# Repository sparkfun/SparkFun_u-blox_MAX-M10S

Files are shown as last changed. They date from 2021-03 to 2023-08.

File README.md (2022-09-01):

SparkFun GNSS Receiver Breakout - MAX-M10S (Qwiic)
===========================================================

SparkFun GNSS Receiver Breakout - MAX-M10S (Qwiic) (https://www.sparkfun.com/products/18037)

[*SparkFun GNSS Receiver Breakout - MAX-M10S (Qwiic) (GPS-18037)*](https://www.sparkfun.com/products/18037)

The SparkFun MAX-M10S Breakout is an ultra-low-power, high performance, miniaturized GNSS board that is perfect for battery operated applications that don't possess a lot of space, such as asset trackers and wearable devices. The MAX-M10S module from u-blox has an extremely low power consumption that is less than 25mW in continuous tracking mode.

The on-board MAX-M10S GNSS receiver can receive signals from the GPS, GLONASS, BeiDou, and Galileo constellations. Thanks to the u-blox Super-S technology, the module offers improved RF sensitivity with small antennas and in non-line-of-sight scenarios. We've included an SMA connector for a sturdy connection when attaching an external antenna. The board is also equipped with an on-board rechargeable battery that provides backup power to the module's RTC. This reduces the time-to-first fix from a cold start (~24s) to a hot start (~1s). The battery will maintain RTC and GNSS orbit data without being connected to power for up to five hours. This increases precision and decreases lock time in battery operated devices without compromising GNSS performance.

Additionally, this u-blox receiver supports I2C which makes it perfect for Qwiic compatibility so we don't have to use up our precious UART ports. Utilizing our handy Qwiic system, no soldering is required to connect it to the rest of your system. However, we still broke out 0.1"-spaced pins in case you prefer to use a breadboard. For users that prefer to communicate over UART, we made sure to configure the UART pin grouping to an industry standard to ensure that it easily connects to a Serial Basic.

U-blox based GNSS products are configurable using the popular Windows program called u-center. Plenty of different functions can be configured on the MAX-M10S: baud rates, update rates, spoofing detection, external interrupts, etc. We've also written an extensive Arduino library for u-blox modules to make reading and controlling the MAX-M10S over our Qwiic Connect System easy. Leave NMEA behind! Start using a much lighter weight binary interface and give your microcontroller (and its one serial port) a break. The SparkFun Arduino library shows how to read latitude, longitude, even heading and speed over I2C without the need for constant serial polling.

Repository Contents
-------------------

* **/Documents** - Related U-blox datasheets and various whitepapers 
* **/Hardware** - Eagle files

Documentation
--------------

* **[Installing an Arduino Library Guide](https://learn.sparkfun.com/tutorials/installing-an-arduino-library)** - Basic information on how to install an Arduino library.
* **[Arduino Library](https://github.com/sparkfun/SparkFun_u-blox_GNSS_Arduino_Library)** - Arduino Library for u-blox modules.
* **[Hookup Guide](https://learn.sparkfun.com/tutorials/1759)** - Hookup guide for the SparkFun GNSS Receiver Breakout - MAX-M10S (Qwiic).

Product Versions
----------------
* [GPS-18037](https://www.sparkfun.com/products/18037)

Version History
---------------
* v1.0 - Initial Release

License Information
-------------------

This product is _**open source**_! 

Various bits of the code have different licenses applied. Anything SparkFun wrote is beerware; if you see me (or any other SparkFun employee) at the local, and you've found our code helpful, please buy us a round!

Please use, reuse, and modify these files as you see fit. Please maintain attribution to SparkFun Electronics and release anything derivative under the same license.

Distributed as-is; no warranty is given.

- Your friends at SparkFun.

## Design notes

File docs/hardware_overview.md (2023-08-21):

We've broken out the u-blox MAX-M10S module to a breakout. This section highlights the relevant features of the board. For more information about the IC, check out the Resources and Going Further.

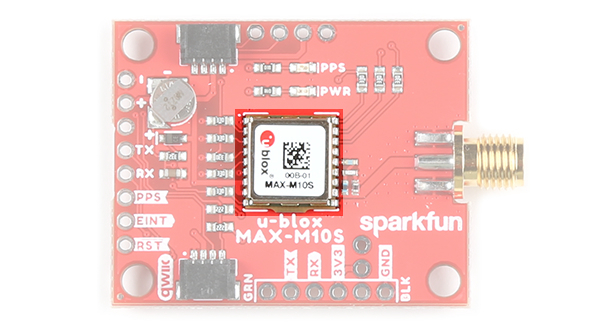
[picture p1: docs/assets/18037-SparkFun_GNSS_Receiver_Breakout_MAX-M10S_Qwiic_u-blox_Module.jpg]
MAX-M10S Highlighted
<div style="text-align: center"></div>

### Power

Power for this board should be **3.3V**. There is a 3.3V pin on the PTH header along the side of the board, but you can also provide power through the Qwiic connector.

<table class="table table-hover table-striped table-bordered">
  <tr style="vertical-align:middle;">
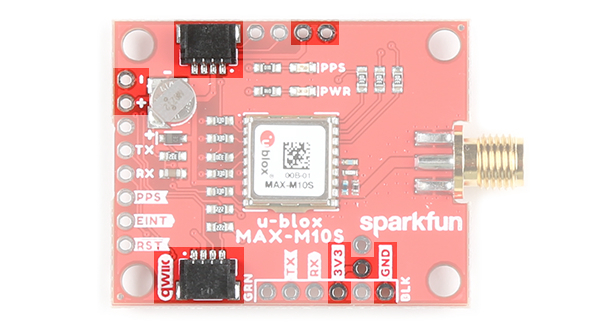
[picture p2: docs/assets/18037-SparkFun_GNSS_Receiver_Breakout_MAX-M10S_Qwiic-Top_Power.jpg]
Top View of Power Highlighted
   <td style="text-align: center; vertical-align: middle;"></td>
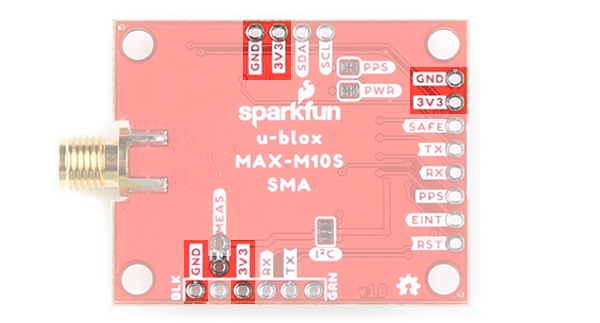
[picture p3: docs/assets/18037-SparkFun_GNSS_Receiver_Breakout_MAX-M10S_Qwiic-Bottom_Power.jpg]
Bottom View of Power Highlighted
   <td style="text-align: center; vertical-align: middle;"></td>
  </tr>
  <tr style="vertical-align:middle;">
  <td style="text-align: center; vertical-align: middle;"><i>Top View</i></td>
  <td style="text-align: center; vertical-align: middle;"><i>Bottom View</i></td>
  </tr>
</table>

### Communication Ports

!!! note
    The MAX-M10S differs from other modules as it only has I<sup>2</sup>C and UART. It is important to note that the board does not have SPI pins.

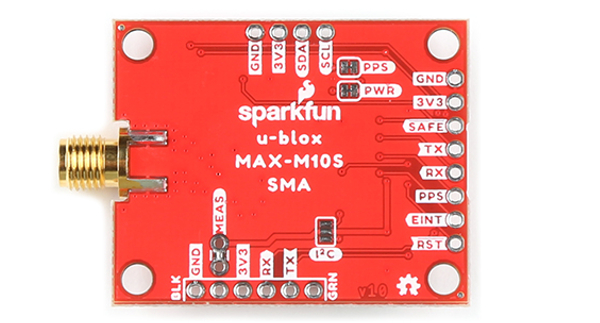
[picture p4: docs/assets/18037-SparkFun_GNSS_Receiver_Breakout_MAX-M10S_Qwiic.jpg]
Back of Board I2C and UART Ports, but no SPI
<div style="text-align: center"></a></div>

### Qwiic and I<sup>2</sup>C (a.k.a. DDC)

There are two PTHs labeled `SDA` and `SCL` which indicates the I<sup>2</sup>C data lines. Similarly, you can just use the Qwiic connector to provide power and connect to the I<sup>2</sup>C pins. The [Qwiic ecosystem](https://www.sparkfun.com/qwiic) is made for fast prototyping by removing the need for soldering. All you need to do is plug a Qwiic cable into the Qwiic connector and voila!

<table class="table table-hover table-striped table-bordered">
  <tr style="vertical-align:middle;">
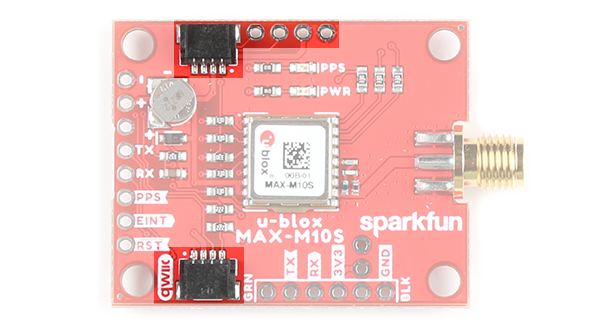
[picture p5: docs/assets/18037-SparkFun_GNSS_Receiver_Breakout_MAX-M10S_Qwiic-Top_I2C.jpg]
Top View of I2C
   <td style="text-align: center; vertical-align: middle;"></td>
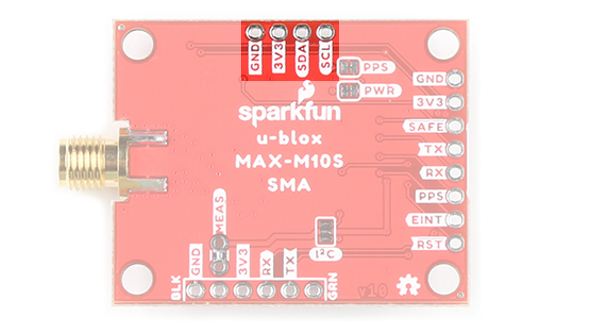
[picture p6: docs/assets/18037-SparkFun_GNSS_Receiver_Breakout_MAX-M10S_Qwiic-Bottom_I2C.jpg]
Bottom View of I2C
   <td style="text-align: center; vertical-align: middle;"></td>
  </tr>
  <tr style="vertical-align:middle;">
  <td style="text-align: center; vertical-align: middle;"><i>Top View</i></td>
  <td style="text-align: center; vertical-align: middle;"><i>Bottom View</i></td>
  </tr>
</table>

!!! note
    The only I2C address for this and all u-Blox GPS products is <b>0x42</b>, though each can have their address changed through software.

### UART

For users that prefer to communicate over UART, we made sure to configure the UART pin grouping to an industry standard to ensure that it easily connects to a [Serial Basic](https://www.sparkfun.com/products/15096). Extra UART pins are also broken out on another edge of the board as well. The port is set to **38400 baud** as the default.

<table class="table table-hover table-striped table-bordered">
  <tr style="vertical-align:middle;">
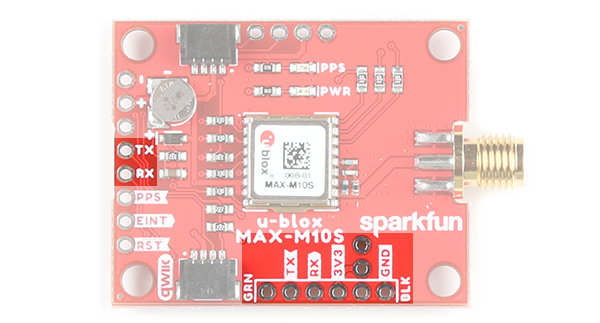
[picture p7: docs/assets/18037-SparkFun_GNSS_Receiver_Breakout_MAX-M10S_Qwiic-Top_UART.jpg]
Top View of UART
   <td style="text-align: center; vertical-align: middle;"></td>
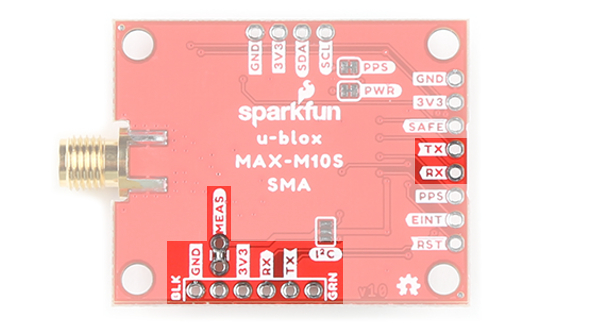
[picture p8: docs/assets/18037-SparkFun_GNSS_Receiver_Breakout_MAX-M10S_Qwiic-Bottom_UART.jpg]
Bottom View of UART
   <td style="text-align: center; vertical-align: middle;"></td>
  </tr>
  <tr style="vertical-align:middle;">
  <td style="text-align: center; vertical-align: middle;"><i>Top View</i></td>
  <td style="text-align: center; vertical-align: middle;"><i>Bottom View</i></td>
  </tr>
</table>

### Control Pins

These pins are used for various extra control of the MAX-M10S. The control pins are highlighted below.

<table class="table table-hover table-striped table-bordered">
  <tr style="vertical-align:middle;">
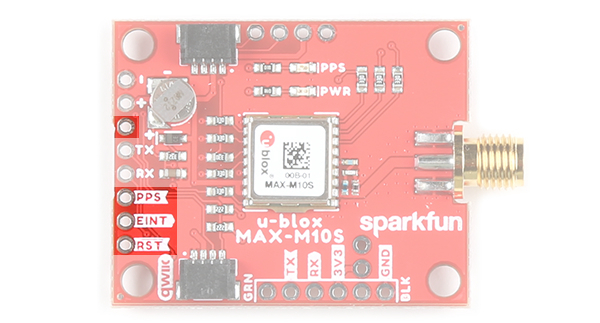
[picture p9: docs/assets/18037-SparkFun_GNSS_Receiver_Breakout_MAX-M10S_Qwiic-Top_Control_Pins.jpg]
Top View of Control Pins
   <td style="text-align: center; vertical-align: middle;"></td>
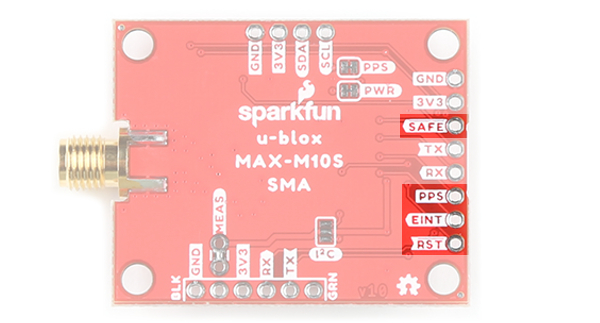
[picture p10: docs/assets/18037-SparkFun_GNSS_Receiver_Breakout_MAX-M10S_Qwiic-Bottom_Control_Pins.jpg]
Bottom View of Control Pins
   <td style="text-align: center; vertical-align: middle;"></td>
  </tr>
  <tr style="vertical-align:middle;">
  <td style="text-align: center; vertical-align: middle;"><i>Top View</i></td>
  <td style="text-align: center; vertical-align: middle;"><i>Bottom View</i></td>
  </tr>
</table>

* **PPS:** Pulse-per-second output pin. Begins blinking at 1Hz when module gets basic GPS/GNSS position lock.
* <b><span style="text-decoration: overline">RST</span>:</b> Reset input pin. Pull this line low to reset the module.
* <b><span style="text-decoration: overline">SAFE</span>:</b> Safeboot input pin. This is required for firmware updates to the module and generally should not be used or connected. To save on space, the silkscreen is labeled on the bottom of the board.
* **EINT:** Interrupt input/output pin. Can be configured using U-Center to bring the module out of deep sleep or to output an interrupt for various module states.

### SMA Connector for Antenna

The board is populated with an SMA connector for a secure connection to a patch antenna.

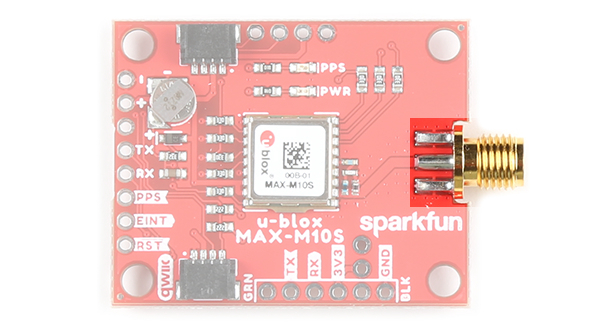
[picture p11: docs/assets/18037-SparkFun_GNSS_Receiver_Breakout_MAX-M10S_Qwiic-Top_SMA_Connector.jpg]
SMA Antenna
<div style="text-align: center"></div>

### LEDs

The board includes two status LEDs as indicated in the image below.

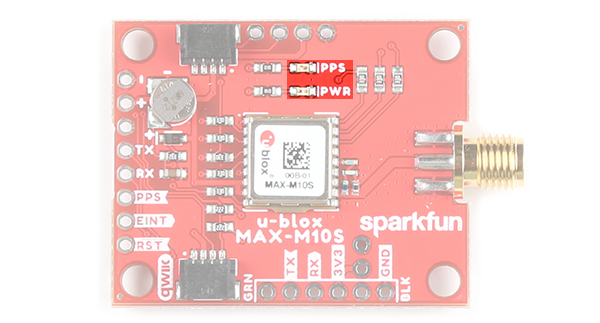
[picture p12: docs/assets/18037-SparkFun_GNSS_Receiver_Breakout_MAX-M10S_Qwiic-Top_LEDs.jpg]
LEDs
<div style="text-align: center"></div>

* **PPS:** The pulse per second LED will illuminate each second once a position lock has been achieved.
* **PWR:** The power LED will illuminate when 3.3V is provided either over the Qwiic bus or any of the 3.3V PTH pins.

### Jumpers

There are four jumpers on the back of the board. For more information, check out our [tutorial on working with jumper pads and PCB traces](https://learn.sparkfun.com/tutorials/how-to-work-with-jumper-pads-and-pcb-traces/all) should you decide to cut the traces with a hobby knife.

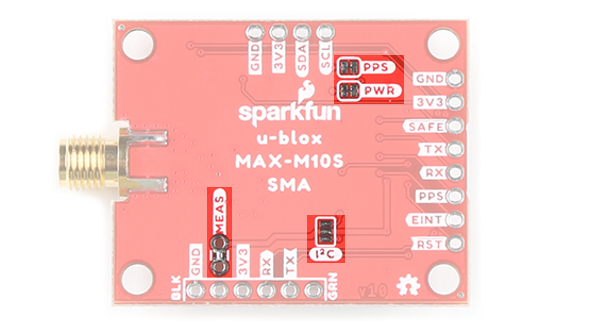
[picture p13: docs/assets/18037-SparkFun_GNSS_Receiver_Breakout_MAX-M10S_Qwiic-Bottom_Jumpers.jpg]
Jumpers
<div style="text-align: center"></div>

* **PWR:** This is connected to the PWR LED on the top of the board. Cutting this disables the LED.
* **MEAS:** Short for current measurement. By default, the MEAs is closed. Cutting the jumper and soldering to the PTH pads will allows you to insert a current meter and precisely monitor the how much current your application is consuming.
* **PPS:** This is connected to the PPS LED on the top of the board. Cutting this disables the LED.
* **I<sup>2</sup>C:** The I<sup>2</sup>C jumpers are open by default. By adding solder to the jumpers, it will connect to the 2.2k&ohm; pull-up resistors for the I<sup>2</sup>C bus.  Most of the time you can leave these alone unless your project requires you to [connect the pull-up resistors](https://learn.sparkfun.com/tutorials/i2c/all#i2c-at-the-hardware-level).

### Backup Battery

The MS621FE rechargeable battery maintains the battery backed RAM (BBR) on the GNSS module. This allows for much faster position locks (a.k.a. hot start). The BBR is also used for module configuration retention. The battery is automatically trickle charged when power is applied and should maintain settings and GNSS orbit data for up to two weeks without power.

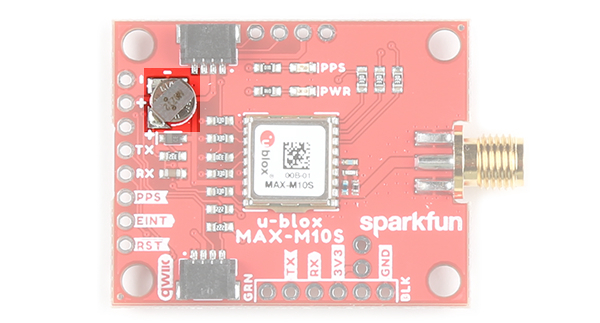
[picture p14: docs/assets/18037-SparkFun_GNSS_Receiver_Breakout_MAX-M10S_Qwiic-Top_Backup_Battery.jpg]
Backup Battery
<div style="text-align: center"></div>

### Board Dimensions

The overall length and width with the antenna connector is about 1.74" x 1.20". There are four mounting holes by each corner of the board.

<div style="text-align: center"><a href="https://cdn.sparkfun.com/assets/e/8/8/9/8/SparkFun_u-blox_MAX-M10S_Board_Dimensions.png">Board Dimensions</a></div>

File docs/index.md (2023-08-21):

<p align="center">
  <a href="https://github.com/sparkfun/SparkFun_u-blox_MAX-M10S/issues" alt="Issues">
    </a>
  <a href="https://github.com/sparkfun/SparkFun_u-blox_MAX-M10SC/actions" alt="Actions">
    </a>
  <a href="https://github.com/sparkfun/SparkFun_u-blox_MAX-M10S/blob/main/LICENSE.md" alt="License">
    </a>
  <a href="https://twitter.com/intent/follow?screen_name=sparkfun">
    </a>
</p>

The [SparkFun u-blox MAX-M10S breakout](https://www.sparkfun.com/products/18037) is an ultra-low-power, high performance, miniaturized GNSS board that is perfect for battery operated applications that don't possess a lot of space, such as asset trackers and wearable devices. In this tutorial, we will quickly get you set up using the Qwiic ecosystem and Arduino so that you can start reading the output!

<div style="text-align: center">
  <table style="border-style:none">
    <tr>
      <td style="text-align: center; vertical-align: middle;">
        <a href="https://www.sparkfun.com/products/18037">
          <div style="text-align: center">SparkFun GNSS Receiver Breakout - MAX-M10S (Qwiic)</div>
          <h3 style="text-align: left">SparkFun GNSS Receiver Breakout - MAX-M10S (Qwiic)
          </h3>
        </a>
        <div style="text-align: left"><span style="text-align: left">GPS-18037</span></div>
      </td>
    </tr>
  </table>
  </div>

<div style="text-align: center"><iframe width="600" height="328" src="https://www.youtube.com/embed/Yh8pLKs7aaY" title="Product Showcase: SparkFun GNSS Receiver MAX-M10S" frameborder="0" allow="accelerometer; autoplay; clipboard-write; encrypted-media; gyroscope; picture-in-picture" allowfullscreen></iframe></div>

### Required Materials

To follow along with this tutorial, you will need the following materials. You may not need everything though depending on what you have. Add it to your cart, read through the guide, and adjust the cart as necessary.

<div>
<table style="border-style:none">
    <tr>
        <td width="140">
            <a href="https://www.sparkfun.com/products/18037">
              <div style="text-align: center">SparkFun GNSS Receiver Breakout - MAX-M10S (Qwiic)</div>
              <h3 style="text-align: left">SparkFun GNSS Receiver Breakout - MAX-M10S (Qwiic)</h3>
            </a>
            <span>GPS-18037</span>
        </td>
        <td width="140">
            <a href="https://www.sparkfun.com/products/14986">
              <div style="text-align: center">GPS/GNSS Magnetic Mount Antenna - 3m (SMA)</div>
              <h3 style="text-align: left">GPS/GNSS Magnetic Mount Antenna - 3m (SMA)</h3>
            </a>
            <span>GPS-14986</span>
        </td>
        <td width="140">
            <a href="https://www.sparkfun.com/products/18158">
              <div style="text-align: center">SparkFun RedBoard Plus</div>
              <h3 style="text-align: left">SparkFun RedBoard Plus</h3>
            </a>
            <span>DEV-18158</span>
        </td>
        <td width="140">
            <a href="https://www.sparkfun.com/products/14426">
              <div style="text-align: center">Qwiic Cable - 50mm</div>
              <h3 style="text-align: left">Qwiic Cable - 50mm</h3>
            </a>
            <span>PRT-14426</span>
        </td>
    </tr>
    <tr>
    <td width="140">
        <a href="https://www.sparkfun.com/products/15424">
          <div style="text-align: center">Reversible USB A to C Cable - 2m</div>
          <h3 style="text-align: left">Reversible USB A to C Cable - 2m</h3>
        </a>
        <span>CAB-15424</span>
    </td>
    </tr>
</table>
</div>

#### Additional GPS Antenna Options

Below are some other GPS antenna options.

<div class="container">
<table style="border-style:none;">
    <tr>
    <td width="140">
        <a href="https://www.sparkfun.com/products/14987">
          <div style="text-align: center">GPS/GNSS Embedded Antenna - 1m (SMA)</div>
          <h3 style="text-align: left">GPS/GNSS Embedded Antenna - 1m (SMA)</h3>
        </a>
        <span>GPS-14987</span>
    </td>
    <td width="140">
        <a href="https://www.sparkfun.com/products/177">
          <div style="text-align: center">GPS Embedded Antenna SMA</div>
            <h3 style="text-align: left">GPS Embedded Antenna SMA</h3>
        </a>
        <span>GPS-00177</span>
    </td>
    </tr>
</table>
</div>

### Suggested Reading

If you aren't familiar with the Qwiic system, we recommend reading [here for an overview](https://www.sparkfun.com/qwiic).

<div style="text-align: center">
<table style="border-style:none">
  <tr>
   <td style="text-align: center; vertical-align: middle;">
   <div style="text-align: center"><a href="https://www.sparkfun.com/qwiic">Qwiic Connect System Click to learn more about the Qwiic Connect System!</a></td></div>
  </tr>
  <tr>
    <td style="text-align: center; vertical-align: middle;"><div style="text-align: center"><i><a href="https://www.sparkfun.com/qwiic">Qwiic Connect System</a></i></div></td>
  </tr>
</table>
</div>

If you aren’t familiar with the following concepts, we also recommend checking out a few of these tutorials before continuing.

<table style="border-style:none">
    <tr>
        <td style="vertical-align: text-top;" width="264px">
            <a href="https://learn.sparkfun.com/tutorials/gps-basics">
            
            <h3 style="text-align: left">GPS Basics
            </h3></a>
        </td>
        <td style="vertical-align: text-top;" width="264px">
            <a href="https://learn.sparkfun.com/tutorials/i2c">
            
            <h3 style="text-align: left">I2C
            </h3></a>
        </td>
        <td style="vertical-align: text-top;" width="264px">
            <a href="https://learn.sparkfun.com/tutorials/serial-basic-hookup-guide">
            
            <h3 style="text-align: left">Serial Basic Hookup Guide
            </h3></a>
        </td>
        <td style="vertical-align: text-top;" width="264px">
            <a href="https://learn.sparkfun.com/tutorials/redboard-plus-hookup-guide">
            
            <h3 style="text-align: left">RedBoard Hookup Guide
            </h3></a>
        </td>
    <tr>
</table>

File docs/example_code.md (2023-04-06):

We're just going to look at example two (i.e. "**Example2_NMEAParsing.ino**") which in my opinion, makes it clear the awesomeness of these GPS receivers. That is to say, talking to satellites and finding out where in the world you are.     

``` c
#include <Wire.h> //Needed for I2C to GPS

#include "SparkFun_u-blox_GNSS_Arduino_Library.h" //Click here to get the library: http://librarymanager/All#SparkFun_u-blox_GNSS
SFE_UBLOX_GNSS myGNSS;

void setup()
{
  Serial.begin(115200);
  Serial.println("SparkFun u-blox Example");

  Wire.begin();

  if (myGNSS.begin() == false)
  {
    Serial.println(F("u-blox GNSS module not detected at default I2C address. Please check wiring. Freezing."));
    while (1);
  }

  //This will pipe all NMEA sentences to the serial port so we can see them
  myGNSS.setNMEAOutputPort(Serial);
}

void loop()
{
  myGNSS.checkUblox(); //See if new data is available. Process bytes as they come in.

  delay(250); //Don't pound too hard on the I2C bus
```

When you upload this code you'll have to wait ~24s to get a lock onto any satellites. After that first lock, the backup battery on the board will provide power to some internal systems that will allow for a **hot start** the next time you turn on the board. The **hot start** only lasts four hours, but allows you to get a lock within one second. After you get a lock the [serial terminal](https://learn.sparkfun.com/tutorials/terminal-basics/arduino-serial-monitor-windows-mac-linux) will start listing longitude and latitude coordinates, as seen below. Make sure to set the serial monitor to **115200 baud**.

<span style="display:block;text-align:center"> This image shows a screenshot of the Arduino Serial terminal spitting out latitude and longitude data. (https://cdn.sparkfun.com/assets/learn_tutorials/8/6/9/nmeaCapture-ublox2.jpg) </span>

<span style="display:block;text-align:center"> _These are the coordinates for SparkFun HQ_ </span>

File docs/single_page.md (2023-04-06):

---
hide:
  - navigation
  - toc
icon: fontawesome/solid/scroll
---

# Introduction
--8<-- "./docs/index.md"

# Hardware Overview
--8<-- "./docs/hardware_overview.md"

# Hardware Assembly
--8<-- "./docs/hardware_assembly.md"

# Software Setup and Programming
--8<-- "./docs/software_setup_and_programming.md"

# Example Code
--8<-- "./docs/example_code.md"

# Troubleshooting Tips
--8<-- "./docs/troubleshooting.md"

# Resources:
--8<-- "./docs/resources_and_going_further.md"

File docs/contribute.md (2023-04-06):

# Contribute: Help Fix our Mistake!
Spot something wrong? Feel free to contribute our open-source design and documentation. 

## Improve our Documentation
All of this documentation can be modified by you! Please help us make it better.

* These pages are contained in the [`docs` folder](https://github.com/sparkfun/SparkFun_u-blox_MAX-M10S/tree/main/docs) of the [SparkFun GNSS Receiver Breakout - MAX-M10S (Qwiic)](https://github.com/sparkfun/SparkFun_u-blox_MAX-M10S) repository.

### Submit a Correction
1. Fork this repo
2. Add your corrections or improvements to the markdown file
3. File a pull request with your changes, and enjoy making the ~~words~~ ~~worlds~~ world a better place.
    * Once received, the documentation specialist will automatically be notified.
    * We will review your suggested improvements to make sure they are correct and fit within our documentation standards.

## Improve our Hardware Design
All of our designs are open-source! Please help us make it better.

* Our board design files are contained in the [`Hardware` folder](https://github.com/sparkfun/SparkFun_u-blox_MAX-M10S/tree/main/Hardware) of the [SparkFun GNSS Receiver Breakout - MAX-M10S (Qwiic)](https://github.com/sparkfun/SparkFun_u-blox_MAX-M10S) repository. 

### Sumbit a Design Improvement
1. Fork this repo
2. Add your design improvements
3. File a pull request with your changes, and enjoy making the ~~words~~ ~~worlds~~ world a better place.
    * Once received, the engineer in charge of the original design will automatically be notified.
    * We will review your suggested improvements, if they are within our board design standards and meet our product design requirements, we will flag these changes for our next board revision. *(Please note, that even if your suggestion is accepted, these changes may not be immediate. We may have to cycle through our current product inventory first.)*

## Contributors
Let's provided some recognition to the contributors for this project!

GitHub Contributors Image
<br>


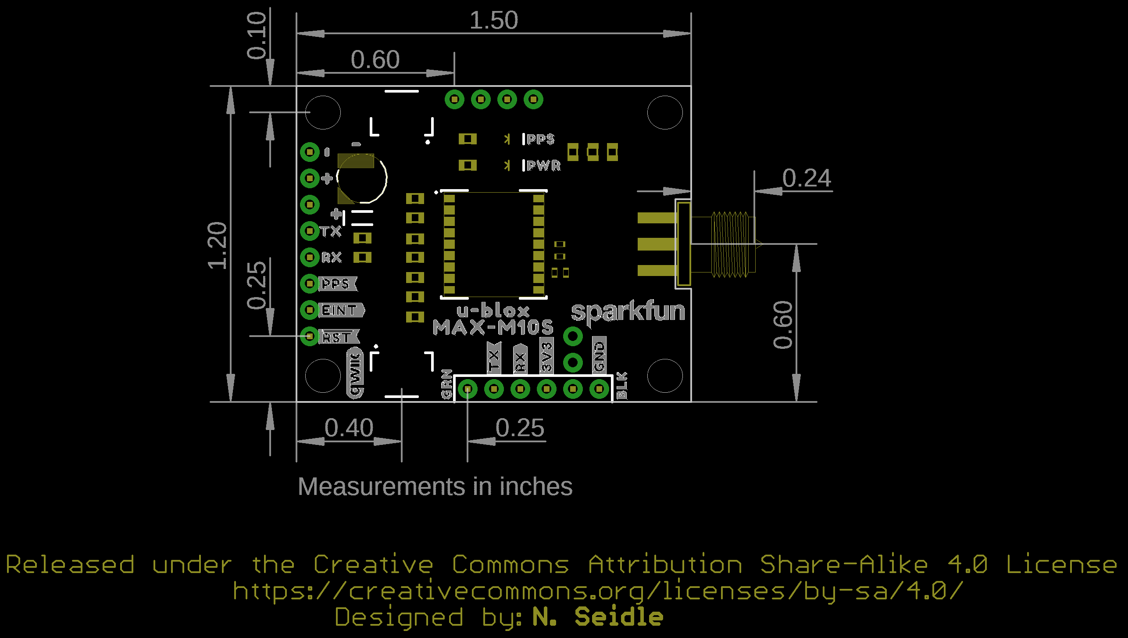
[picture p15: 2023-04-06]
Hardware/SparkFun_u-blox_MAX-M10S_Board_Dimensions.png

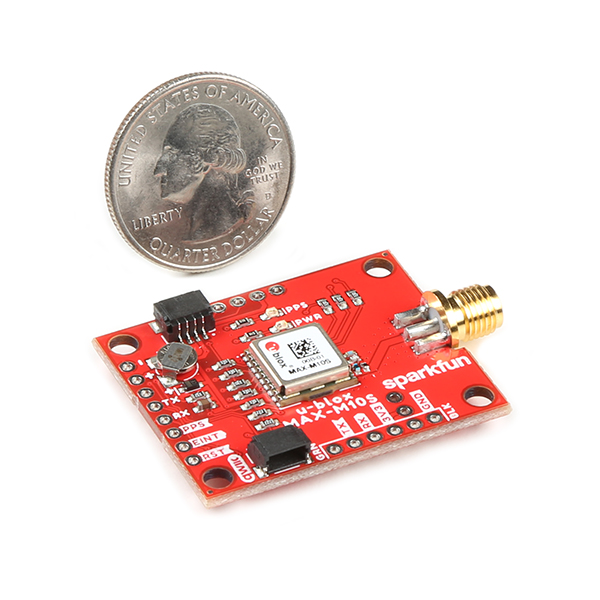
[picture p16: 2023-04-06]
docs/assets/18037-SparkFun_GNSS_Receiver_Breakout_-_MAX-M10S__Qwiic_-04.jpg

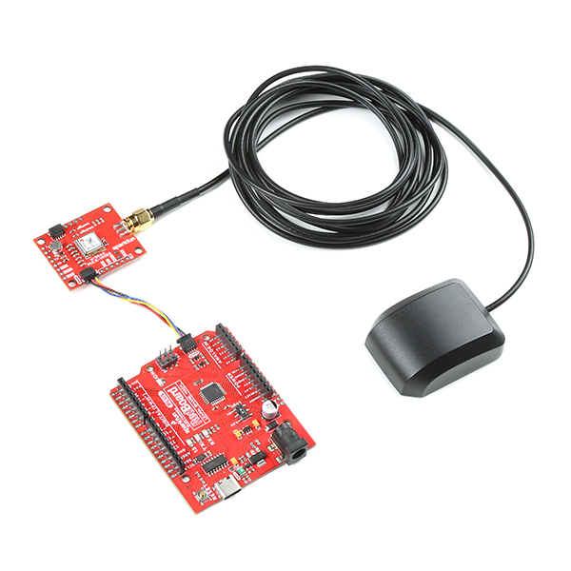
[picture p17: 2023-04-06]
docs/assets/18037-SparkFun_GNSS_Receiver_Breakout_-_MAX-M10S__Qwiic_-05.jpg

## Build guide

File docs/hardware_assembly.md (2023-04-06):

At a minimum, you will need to attach an external antenna to the MAX-M10S, supply 3.3V power, and connect to one of the board's peripherals.

### Attaching an External Antenna

Plug in one of our patch antennas with SMA connector to the GPS board. Secure the connection using the hex nut until it is finger-tight.

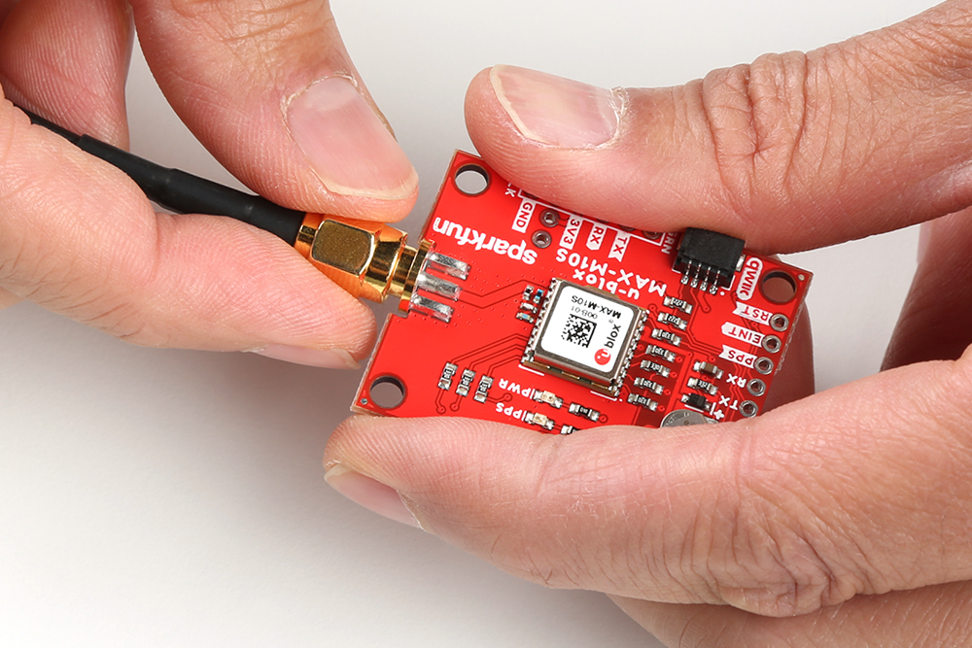
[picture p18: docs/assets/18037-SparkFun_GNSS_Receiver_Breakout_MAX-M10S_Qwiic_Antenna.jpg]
Finger Tightening the SMA GPS Antenna to the MAX-M10S
<div class="center-block text-center"></div>

### I<sup>2</sup>C

One method to communicate with the MAX-M10S is through I<sup>2</sup>C. The Qwiic connect system makes it quick and easy to connect the board to your system using a polarized cable. For embedded projects, you can use a Qwiic-enabled Arduino development board like the [RedBoard Plus](https://www.sparkfun.com/products/18158) and its [associated USB cable](https://www.sparkfun.com/products/15425). Then plug a Qwiic cable between the RedBoard Plus and the SparkFun MAX-M10S.

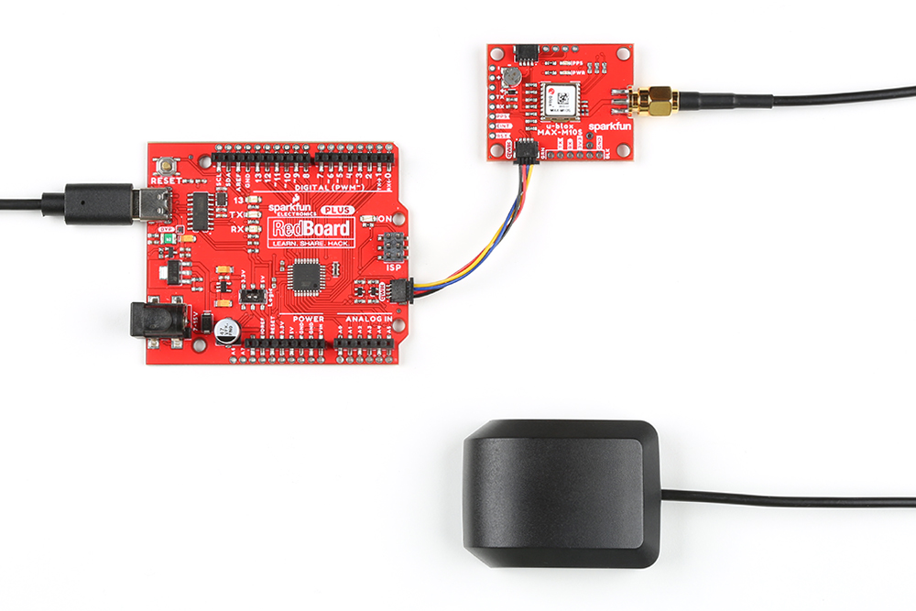
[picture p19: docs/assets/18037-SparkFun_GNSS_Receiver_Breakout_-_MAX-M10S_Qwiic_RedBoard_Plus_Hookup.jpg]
RedBoard Plus Connected to the MAX-M10S via Qwiic Cable
<div class="center-block text-center"></div>

!!! note
    The RedBoard Plus includes a switch to adjust the logic levels to either 5V or 3.3V. It does not matter what side the switch is on for this setup to communicate with the MAX-M10S since there are logic level converters included before the Qwiic connector.

If you're going to be [soldering](https://learn.sparkfun.com/tutorials/how-to-solder-through-hole-soldering) to the through hole pins for I<sup>2</sup>C functionality, then just attach the following lines between your chosen microcontroller's I<sup>2</sup>C and the MAX-M10S:

* SDA to SDA
* SCL to SCL
* 3.3V to 3.3V
* GND to GND

### UART

A second method to communicate with the MAX-M10S is through its serial UART. You can directly connect the GPS to the computer by connecting a USB-to-serial converter to the industry standard serial connection (aka the 'FTDI' pinout). In this case, we used an FTDI but you can use another USB-to-serial converter like the CH340. Just make sure to match the silkscreen (GRN to GRN and BLK to BLK). For a secure connection, you&apos;ll need to [solder](https://learn.sparkfun.com/tutorials/how-to-solder-through-hole-soldering) male header pins or wires to the MAX-M10S.

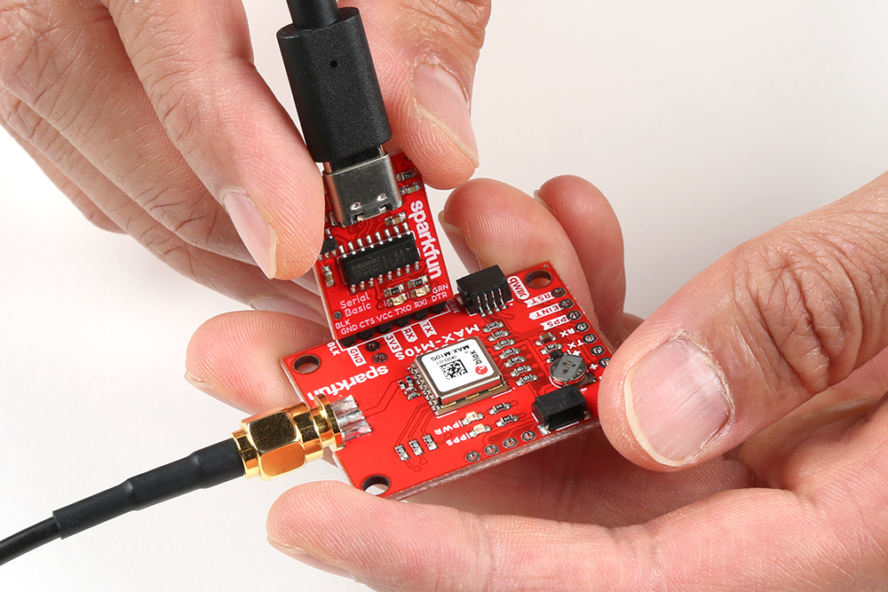
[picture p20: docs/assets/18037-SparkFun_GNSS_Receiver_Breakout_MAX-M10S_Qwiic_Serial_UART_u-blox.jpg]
USB-to-Serial Converter to MAX-M10S
<div class="center-block text-center"></div>

You could also connect the pins to a microcontroller like the RedBoard Plus as long as the switch for the logic levels are flipped to the 3.3V side before powering the board up. You'll need to do a little bit more work as opposed to using Qwiic connect system. You'll need to attach the following lines between your chosen microcontroller's UART and the MAX-M10S:

* Tx to Rx
* Rx to Tx
* 3.3V to 3.3V
* GND to GND

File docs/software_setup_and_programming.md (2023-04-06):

!!! note
    This example assumes you are using the latest version of the Arduino IDE on your desktop. If this is your first time using Arduino, please review our tutorial on <a href="https://learn.sparkfun.com/tutorials/installing-arduino-ide">installing the Arduino IDE.</a> If you have not previously installed an Arduino library, please check out our <a href="https://learn.sparkfun.com/tutorials/installing-an-arduino-library">installation guide.</a>

    If you've never connected an FTDI or CH340 to your computer before, you may need to install drivers for the USB-to-serial converter. Check out our <a href="https://learn.sparkfun.com/tutorials/how-to-install-ftdi-drivers">How to Install FTDI Drivers</a> or <a href="https://learn.sparkfun.com/tutorials/sparkfun-serial-basic-ch340c-hookup-guide#drivers-if-you-need-them">How to Install CH340 Drivers</a> tutorial for help with the installation.

All of our u-blox based GPS boards share the same library: this board, their [predeccesors](https://learn.sparkfun.com/tutorials/sparkfun-gps-breakout-zoe-m8q-and-sam-m8q-hookup-guide) and the higher [precision](https://www.sparkfun.com/products/15005) [u-blox cousins](https://www.sparkfun.com/products/15136). The SparkFun u-blox Arduino library can be downloaded with the Arduino library manager by searching '**SparkFun u-blox GNSS**' or you can grab the zip here from the [GitHub repository](https://github.com/sparkfun/SparkFun_u-blox_GNSS_Arduino_Library) to manually install:

<div style="text-align: center"><a href="https://github.com/sparkfun/SparkFun_u-blox_GNSS_Arduino_Library/archive/main.zip" class="md-button">SparkFun U-blox Arduino Library (ZIP)</a></div>

There are several example sketches provided that utilize the I<sup>2</sup>C bus to get you up and receiving messages from space. We&apos;ll go over one of the examples in this tutorial.

!!! note
    Example 2 uses the '<b>MicroNMEA</b>' library by <b>Steve Marple</b>. Make sure to install the library as well by searching for it in the Arduino library manager. You could also grab the zip here from the <a href="https://github.com/stevemarple/MicroNMEA">GitHub repository</a> to manually install.

    <div style="text-align: center">
    [MicroNMEA Arduino Library (ZIP)](https://github.com/stevemarple/MicroNMEA/archive/master.zip){ .md-button }</div>

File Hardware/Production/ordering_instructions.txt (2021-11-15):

panel size, 168x138mm
PCB thickness, 1.6mm
number of layers, 2
soldermask color, Red
silkscreen color, White
oz copper, 1oz
finish, HASL lead free
stencils, none
pcs per panel, 16
min trace width, 0.1778mm / 0.0070in
min drill size, 0.3048mm / 0.0120in

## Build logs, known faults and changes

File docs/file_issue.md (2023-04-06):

# Did we make a mistake?

Spot something wrong? Please let us know. 

!!! attention
    This is not where customers should seek assistance on a product. If you require technical assistance or have questions about a product that is not working as expected, please head over to the [SparkFun Technical Assistance](https://www.sparkfun.com/technical_assistance) page for some initial troubleshooting.
    <center>
    [SparkFun Technical Assistance Page](https://www.sparkfun.com/technical_assistance){ .md-button .md-button--primary }
    </center>
    
    If you can't find what you need there, you'll need a [Forum Account](https://forum.sparkfun.com/ucp.php?mode=register) to search product forums and post questions.

## Discrepancies in the Documentation

All of this documentation can be modified by you! Please help us make it better.

* The documentation files for these pages are contained in the [`docs` folder](https://github.com/sparkfun/SparkFun_u-blox_MAX-M10S/tree/main/docs) of the [SparkFun u-blox MAX-M10S](https://github.com/sparkfun/SparkFun_u-blox_MAX-M10S) repository.

### Spot something wrong?
If a section of the documentation is incorrect, please [open an issue](https://github.com/sparkfun/SparkFun_u-blox_MAX-M10S/issues) and let us know.

### Do you have a suggested correction?
1. With a GitHub account, fork this repo
2. Add your correction(s) or improvement(s) to the markdown file(s)
3. File a pull request with your changes, and enjoy making the ~~words~~ ~~worlds~~ world a better place.
    * Once received, the documentation specialist will automatically be notified.
    * We will review your suggested improvement(s) to make sure they are correct and fit within our documentation standards.

## Problems in the Hardware Design

All of our designs are open-source! Please help us make it better.

* Our board design files are contained in the [`Hardware` folder](https://github.com/sparkfun/SparkFun_u-blox_MAX-M10S/tree/main/Hardware) of the [SparkFun u-blox MAX-M10S](https://github.com/sparkfun/SparkFun_u-blox_MAX-M10S) repository. 

### Does something not make sense?
If part of the design is confusing, please [open an issue](https://github.com/sparkfun/SparkFun_USB-C_Host_Shield/issues) and let us know.

### Did we forget to include an important function of the board?
* Please keep in mind that we may intentionally exclude certain functions of the board to meet our product design requirements. *(For example, our Qwiic Micro boards are intended to fit on a small board layout and only use I<sup>2</sup>C communication; therefore, we may not have the SPI and interrupt pins available for users.)*
* If part of the board's functionality is missing, please [open an issue](https://github.com/sparkfun/SparkFun_u-blox_MAX-M10S/issues) and file a feature request.

### Do you wish to contribute directly to improving the board design?
1. With a GitHub account, Fork this repo
2. Add your design improvement(s)
3. File a pull request with your changes, and enjoy making the ~~words~~ ~~worlds~~ world a better place.
    * Once received, the engineer in charge of the original design will automatically be notified.
    * We will review your suggested improvement(s), if they are within our board design standards and meet our product design requirements, we will flag these changes for our next board revision. *(Please note, that even if your suggestion is accepted, these changes may not be immediate. We may have to cycle through our current product inventory first.)*

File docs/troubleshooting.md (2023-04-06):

!!! note
    <span class="glyphicon glyphicon-question-sign" aria-hidden="true"></span>
        <strong> Not working as expected and need help? </strong> <br /><br />

    If you need technical assistance and more information on a product that is not working as you expected, we recommend heading on over to the <a href="https://www.sparkfun.com/technical_assistance">SparkFun Technical Assistance</a> page for some initial troubleshooting. <br /><br />

    <div style="text-align: center"><a href="https://www.sparkfun.com/technical_assistance" target="sfe_technical_assistance" class="md-button">SparkFun Technical Assistance Page</a></div>

    If you don't find what you need there, the <a href="https://forum.sparkfun.com/index.php">SparkFun Forums</a> are a great place to find and ask for help. If this is your first visit, you'll need to <a href="https://forum.sparkfun.com/ucp.php?mode=register">create a Forum Account</a> to search product forums and post questions.<br /><br />

    <div style="text-align: center"><a href="https://forum.sparkfun.com/ucp.php?mode=register" class="md-button">Create New Forum Account</a>&nbsp;&nbsp;&nbsp;<a href="https://forum.sparkfun.com/index.php" class="md-button md-button--primary">Log Into SparkFun Forums</a></div>

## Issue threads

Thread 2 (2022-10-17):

Add support for VIO_SEL pin to select 1.8V operation

grunzasr, 2022-10-17:
Pin 15 is floated (as in your design) for 3.3V IO.  Pin 15 grounded is for 1.8V IO.  Revision 3 of the datasheet has this in Table 9: MAX-M10S pin assignment on page 9.

If you add two holes for a 2-pin 0.1” jumper to be installed (and a way to disconnect the battery) then the module could be used at 1.8V easily.  Just a suggestion in case you ever update the artwork or build a new batch of boads.

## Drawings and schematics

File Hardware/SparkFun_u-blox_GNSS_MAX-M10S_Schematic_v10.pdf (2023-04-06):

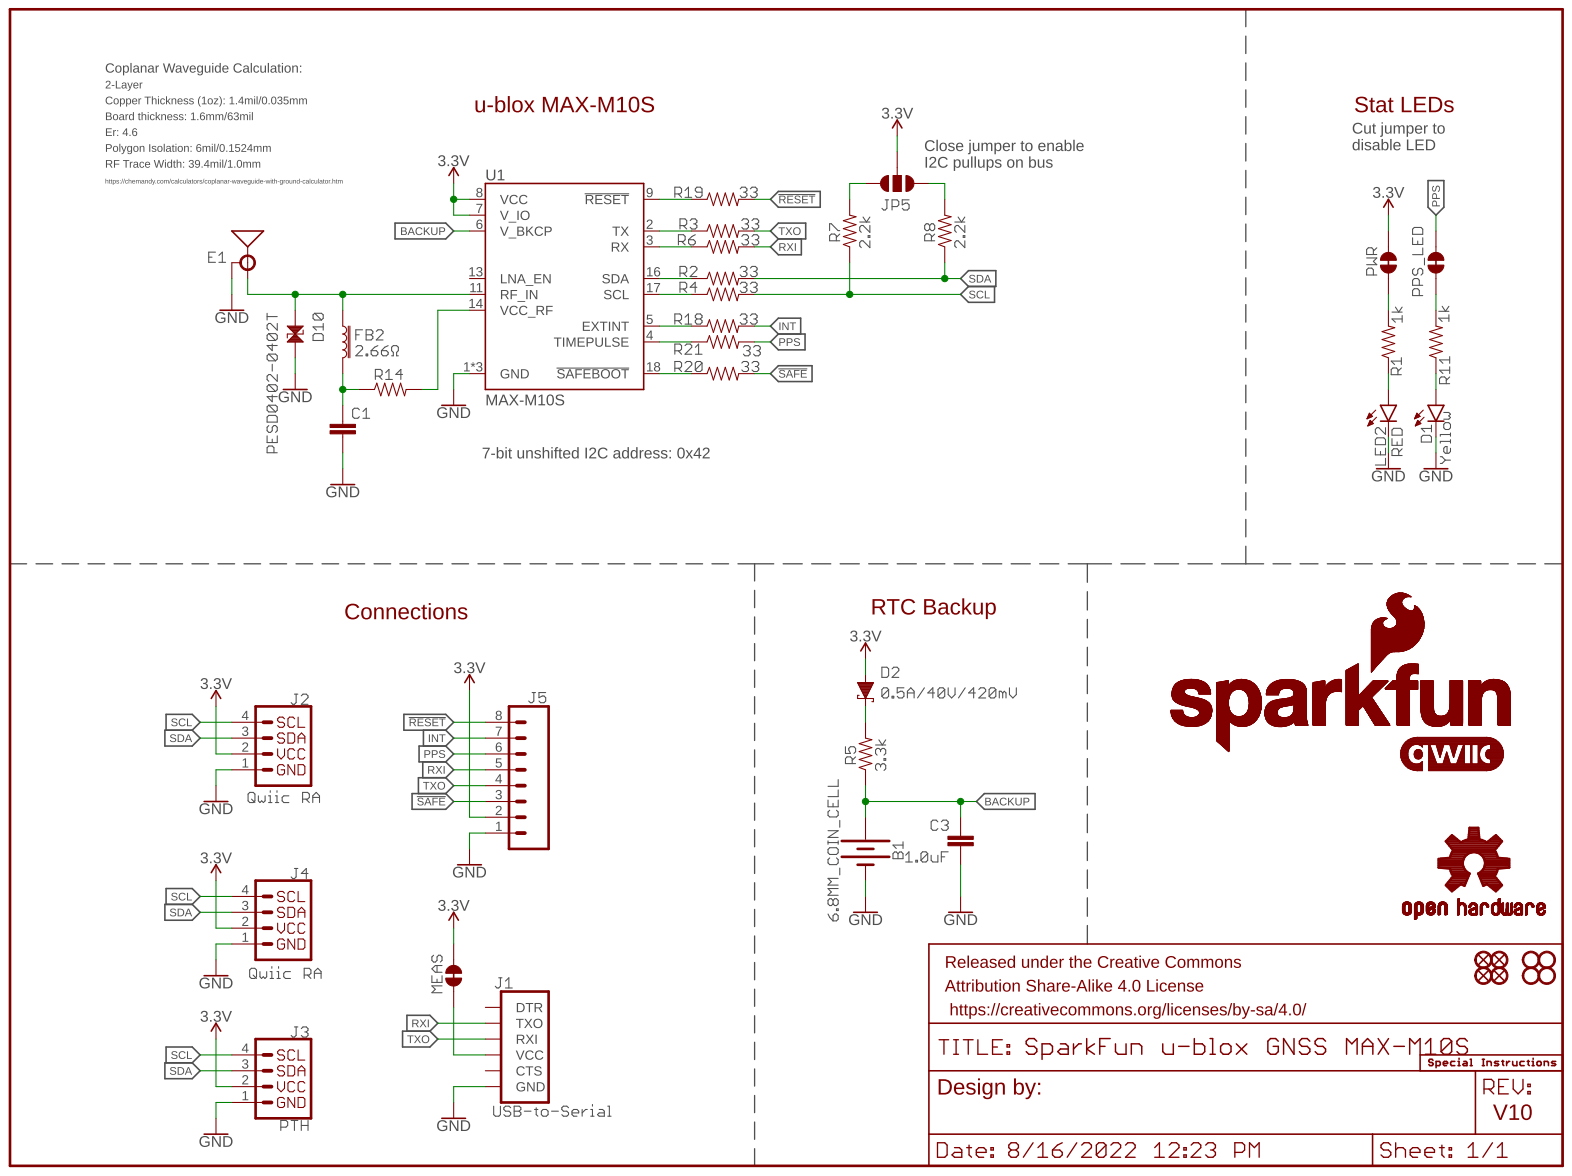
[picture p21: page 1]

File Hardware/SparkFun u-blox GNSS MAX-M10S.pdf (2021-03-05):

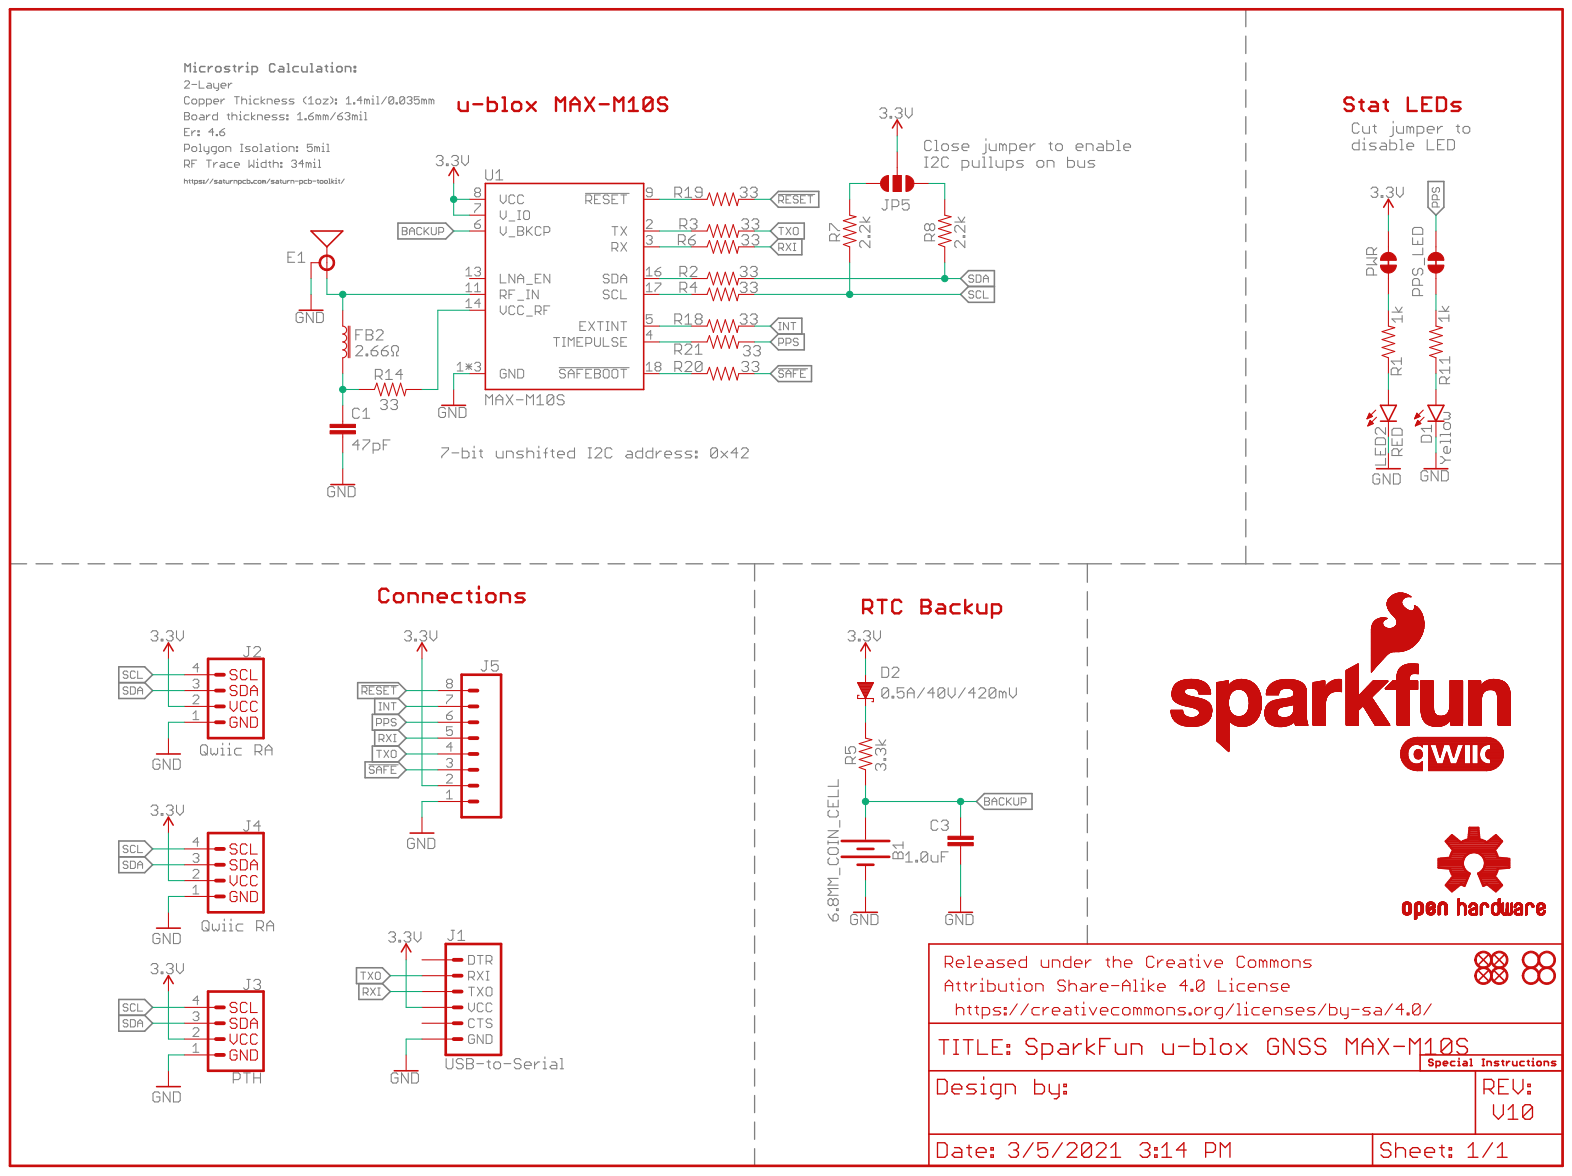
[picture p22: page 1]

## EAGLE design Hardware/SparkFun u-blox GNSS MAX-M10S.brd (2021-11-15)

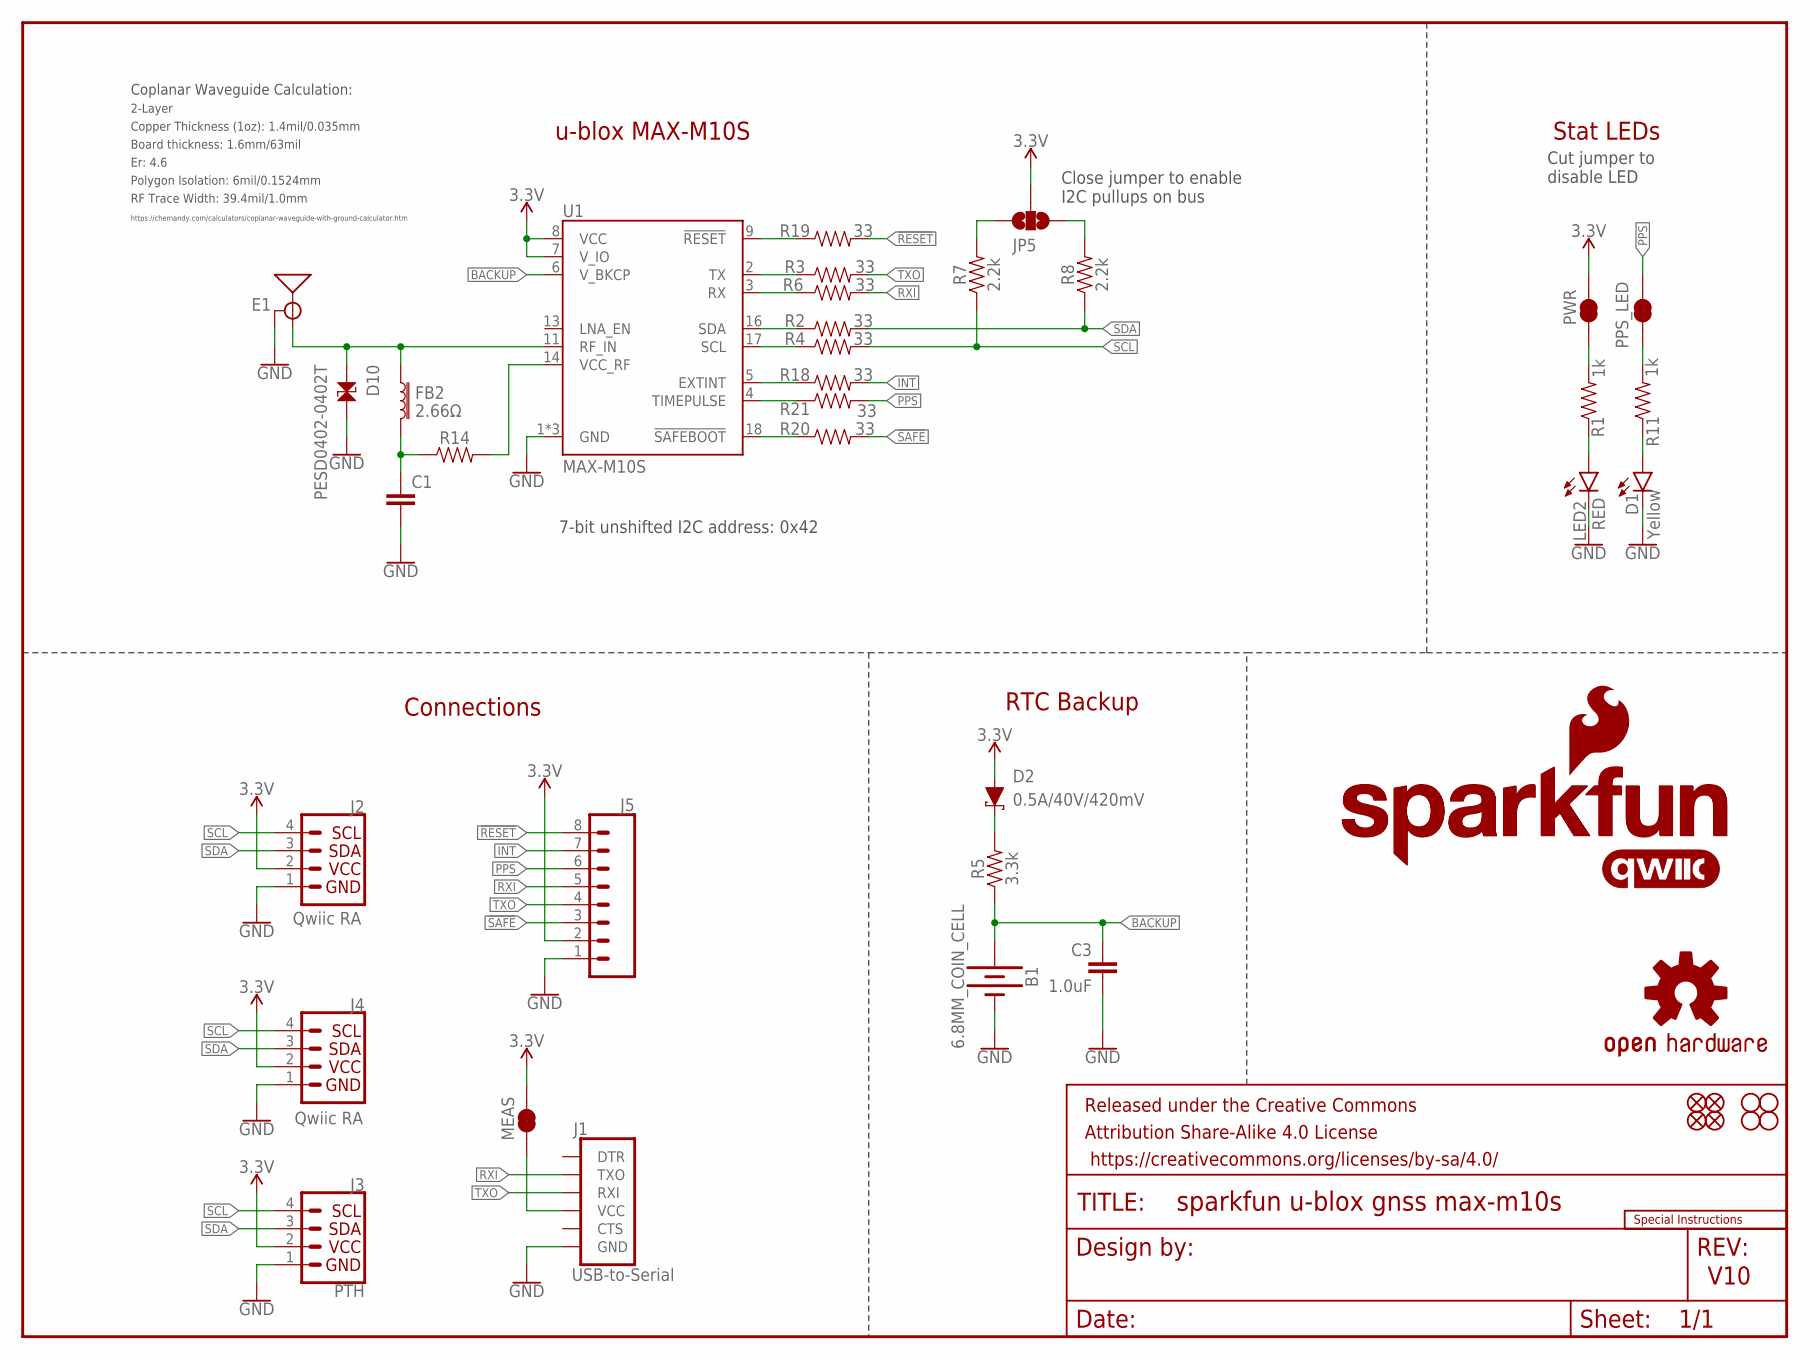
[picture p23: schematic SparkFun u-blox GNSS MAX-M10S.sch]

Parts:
B1: 6.8MM_COIN_CELL; ML414H_IV01E
C1: 47pF; 0402-TIGHT
C3: 1.0uF; 0603
D1: Yellow; LED-0603
D2: 0.5A/40V/420mV; SOD-323
D10: PESD0402-0402T; 0402-TIGHT
E1: ANTENNA-SMA-GROUNDEDEDGE_SMA; SMA-EDGE
FB2: 2.66Ω; 0402-TIGHT
FD1, FD2, FD3, FD4: FIDUCIALUFIDUCIAL; FIDUCIAL-MICRO
FRAME1: FRAME-LETTER; CREATIVE_COMMONS
H1, H2, H3, H4: STAND-OFF
J1: USB-to-Serial; 1X06_NO_SILK
J2, J4: Qwiic RA; JST04_1MM_RA
J3: PTH; 1X04_NO_SILK
J5: CONN_08NO_SILK_DNP; 1X08_NO_SILK
JP5: JUMPER-SMT_3_NO_SILK; SMT-JUMPER_3_NO_SILK
LED2: RED; LED-0603
LOGO1: OSHW-LOGOMINI; OSHW-LOGO-MINI
LOGO2: SFE_LOGO_NAME_FLAME.1_INCH; SFE_LOGO_NAME_FLAME_.1
LOGO3: QWIIC_LOGO_5MM; QWIIC_5MM
LOGO4: SFE_LOGO_NAME.1_INCH; SFE_LOGO_NAME_.1
MEAS: JUMPER-COMBO_2_NC_TRACE; COMBO-JUMPER_2_NC_TRACE
PPS_LED: JUMPER-SMT_2_NC_TRACE_SILK; SMT-JUMPER_2_NC_TRACE_SILK
PWR: JUMPER-SMT_2_NC_TRACE_SILK; SMT-JUMPER_2_NC_TRACE_SILK
R1, R11: 1k; 0603
R2, R3, R4, R6, R18, R19, R20, R21: 33; 0603
R5: 3.3k; 0603
R7, R8: 2.2k; 0603
R14: 33OHM-0402T-1/10W-1%; 0402-TIGHT
U1: MAX-M10S
U$2: SPECIAL_INSTRUCTIONS-ORDERING; ORDERING_INSTRUCTIONS

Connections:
3.3V: D2.A, J2.2, J3.2 (VCC), J4.2, J5.2, JP5.2, MEAS.2, MEAS.4 (2), PWR.2, U1.7 (V_IO), U1.8 (VCC)
!RESET: J5.8, R19.2
!SAFE: J5.3, R20.2
ANT_VCC: C1.1, FB2.2, R14.1
BACKUP: B1.+, C3.1, R5.1, U1.6 (V_BKCP)
EXTINT_LV: R18.1, U1.5 (EXTINT)
GND: B1.-, C1.2, C3.2, D1.C, D10.2, E1.GND@0 (GND), E1.GND@1 (GND), E1.GND@2 (GND), E1.GND@3 (GND), J1.6 (GND), J2.1, J3.1 (GND), J4.1, J5.1, LED2.C, U1.1 (GND), U1.10 (GND), U1.12 (GND)
GPS_RF: D10.1, E1.SIG (SIGNAL), FB2.1, U1.11 (RF_IN)
INT: J5.7, R18.2
unnamed: J1.4 (VCC), MEAS.1, MEAS.3 (1)
unnamed: D1.A, R11.1
unnamed: PPS_LED.1, R11.2
unnamed: JP5.1, R8.2
unnamed: D2.C, R5.2
unnamed: JP5.3, R7.2
unnamed: LED2.A, R1.1
unnamed: PWR.1, R1.2
PPS: J5.6, PPS_LED.2, R21.2
PPS_LV: R21.1, U1.4 (TIMEPULSE)
RST_LV: R19.1, U1.9 (!RESET!)
RXI: J1.3 (TXO), J5.5, R6.2
RXLV: R6.1, U1.3 (RX)
SAFE_LV: R20.1, U1.18 (!SAFEBOOT!)
SCL: J2.4, J3.4 (SCL), J4.4, R4.2, R7.1
SCL_LV: R4.1, U1.17 (SCL)
SDA: J2.3, J3.3 (SDA), J4.3, R2.2, R8.1
SDA_LV: R2.1, U1.16 (SDA)
TXLV: R3.1, U1.2 (TX)
TXO: J1.2 (RXI), J5.4, R3.2
VCC_RF: R14.2, U1.14 (VCC_RF)

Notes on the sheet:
V10
7-bit unshifted I2C address: 0x42
u-blox MAX-M10S
RTC Backup
Stat LEDs
Close jumper to enable I2C pullups on bus
Cut jumper to disable LED
Coplanar Waveguide Calculation:
Connections
Board thickness: 1.6mm/63mil
Er: 4.6
Copper Thickness (1oz): 1.4mil/0.035mm
RF Trace Width: 39.4mil/1.0mm
Polygon Isolation: 6mil/0.1524mm
2-Layer
https://chemandy.com/calculators/coplanar-waveguide-with-ground-calculator.htm

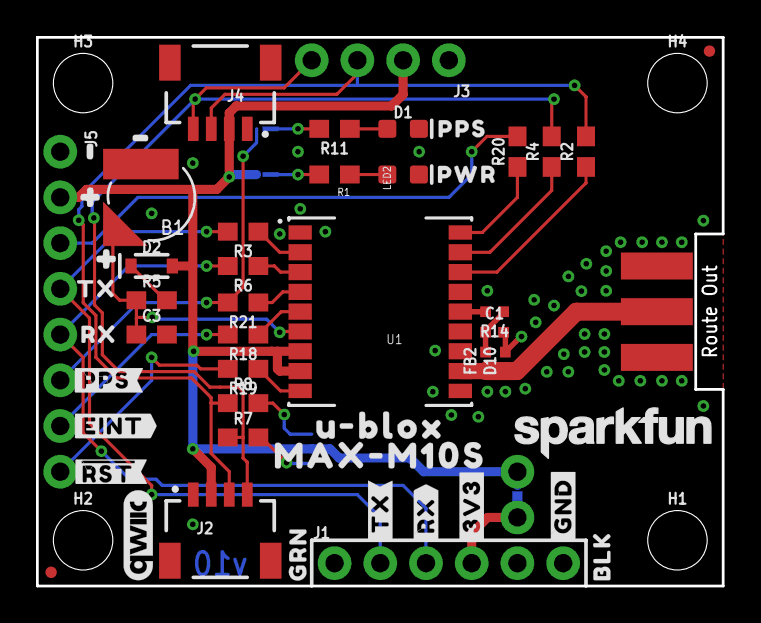
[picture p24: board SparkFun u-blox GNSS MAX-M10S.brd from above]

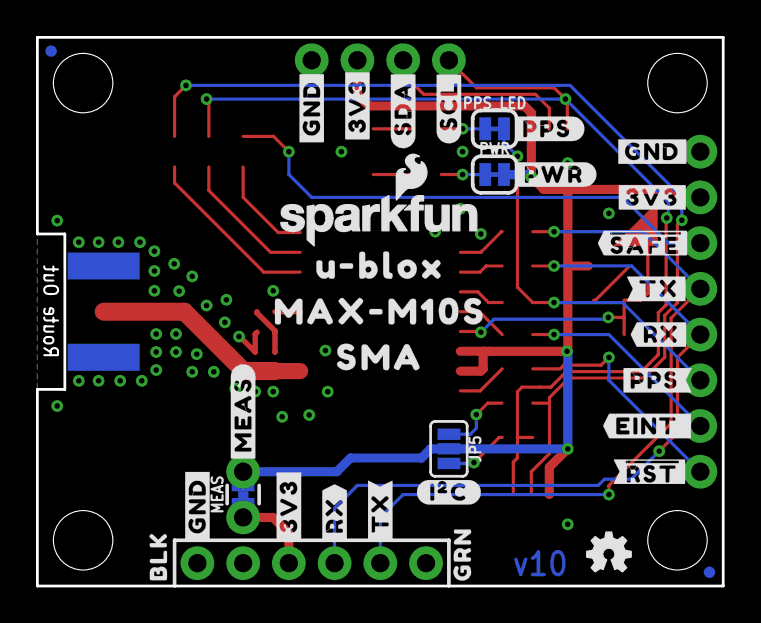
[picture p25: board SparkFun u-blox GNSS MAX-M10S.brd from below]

Board: 2 copper layers, 38.1 x 30.5 mm, 91 parts (33 on the bottom side), 30 nets.

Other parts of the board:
U$1, U$10, U$26, U$31: #3V3#4
U$3, U$11, U$27, U$34: #GND#5
U$4, U$28: BLK0
U$5, U$29: GRN1
U$6: PPS7
U$7: PWR6
U$8, U$25: #RX#2
U$9, U$22: #TX#3
U$12: ##RST##2
U$13: ##SAFE##0
U$14, U$43: #PPS#1
U$15: #RX#1
U$16: #TX#0
U$18, U$23: MAX#M10S1
U$19, U$37: #0
U$20, U$21: U#BLOX0
U$24: SMA2
U$30: #I�C#0
U$32: #SCL#1
U$33: #SDA#0
U$35: #PPS#0
U$36: #PWR#0
U$38, U$40: #1
U$39: ##RST##0
U$41: #MEAS#0
U$42: #EINT#0
U$44: RX2
U$45: TX3
U$46: #EINT_#0

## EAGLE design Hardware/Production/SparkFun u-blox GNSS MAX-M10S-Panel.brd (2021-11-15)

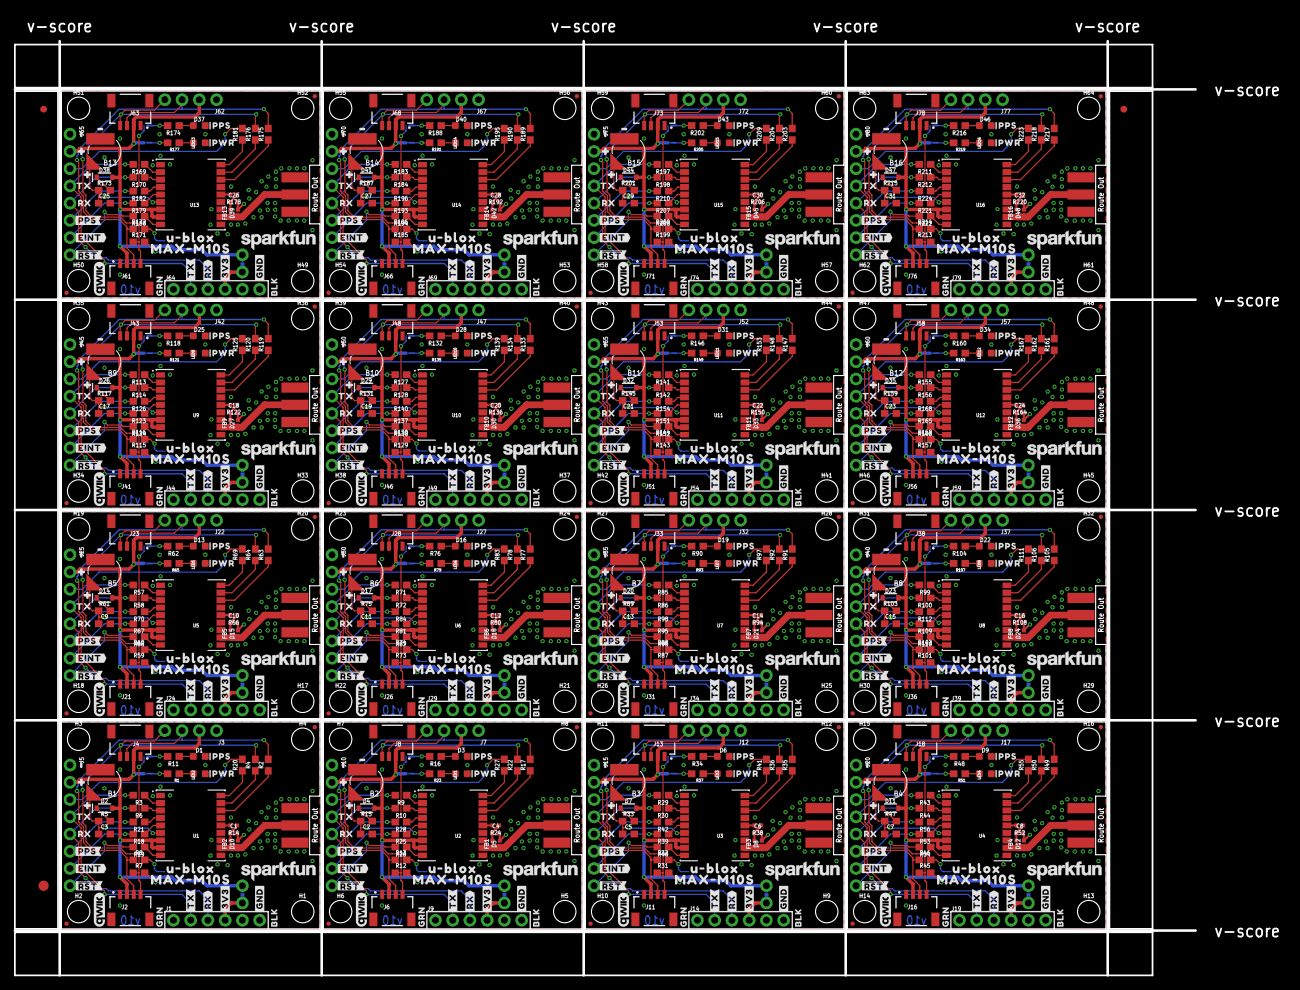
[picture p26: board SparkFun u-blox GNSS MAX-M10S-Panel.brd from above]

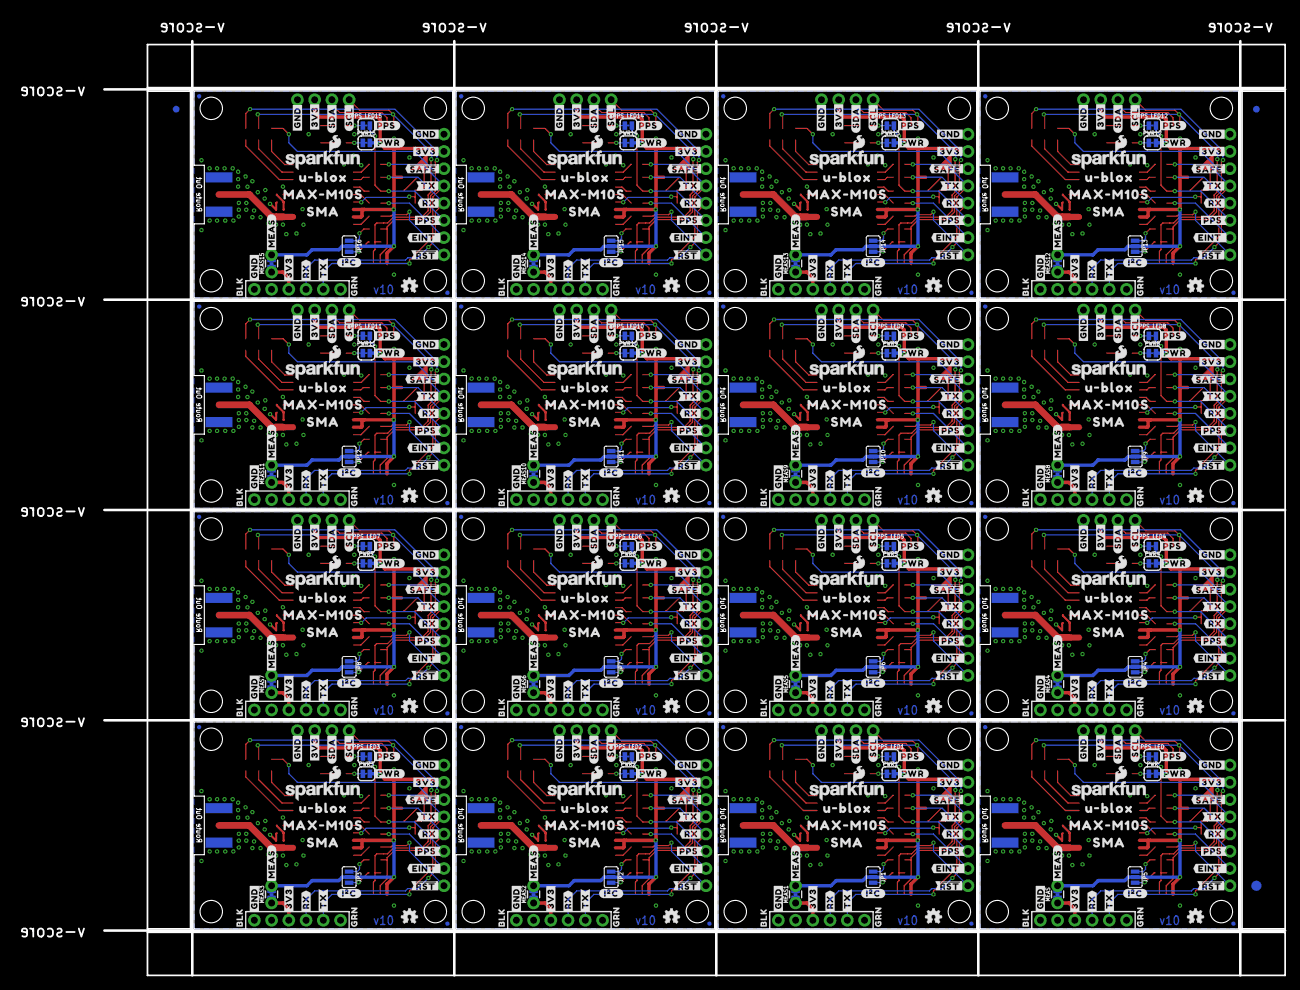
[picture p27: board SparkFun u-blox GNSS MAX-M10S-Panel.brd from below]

Board: 2 copper layers, 174.0 x 137.7 mm, 1430 parts (531 on the bottom side), 480 nets.

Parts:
B1, B2, B3, B4, B5, B6, B7, B8, B9, B10, B11, B12, B13, B14, B15, B16: 6.8MM_COIN_CELL; ML414H_IV01E
C1, C4, C6, C8, C10, C12, C14, C16, C18, C20, C22, C24, C26, C28, C30, C32: 47pF; 0402-TIGHT
C2, C3, C5, C7, C9, C11, C13, C15, C17, C19, C21, C23, C25, C27, C29, C31: 1.0uF; 0603
D1, D3, D6, D9, D13, D16, D19, D22, D25, D28, D31, D34, D37, D40, D43, D46: Yellow; LED-0603
D2, D4, D7, D11, D14, D17, D20, D23, D26, D29, D32, D35, D38, D41, D44, D47: 0.5A/40V/420mV; SOD-323
D5, D8, D10, D12, D15, D18, D21, D24, D27, D30, D33, D36, D39, D42, D45, D48: PESD0402-0402T; 0402-TIGHT
E1, E2, E3, E4, E5, E6, E7, E8, E9, E10, E11, E12, E13, E14, E15, E16: ANTENNA-SMA-GROUNDEDEDGE_SMA; SMA-EDGE
E$1, E$2, E$3, E$4: FIDUCIAL-1X2
E$5, E$6: FIDUCIAL-1.5X3
FB1, FB2, FB3, FB4, FB5, FB6, FB7, FB8, FB9, FB10, FB11, FB12, FB13, FB14, FB15, FB16: 2.66Ω; 0402-TIGHT
FD1, FD2, FD3, FD4, FD5, FD6, FD7, FD8, FD9, FD10, FD11, FD12, FD13, FD14, FD15, FD16, FD17, FD18, FD19, FD20, FD21, FD22, FD23, FD24, FD25, FD26, FD27, FD28, FD29, FD30, FD31, FD32, FD33, FD34, FD35, FD36, FD37, FD38, FD39, FD40, FD41, FD42, FD43, FD44, FD45, FD46, FD47, FD48, FD49, FD50, FD51, FD52, FD53, FD54, FD55, FD56, FD57, FD58, FD59, FD60, FD61, FD62, FD63, FD64: FIDUCIALUFIDUCIAL; FIDUCIAL-MICRO
H1, H2, H3, H4, H5, H6, H7, H8, H9, H10, H11, H12, H13, H14, H15, H16, H17, H18, H19, H20, H21, H22, H23, H24, H25, H26, H27, H28, H29, H30, H31, H32, H33, H34, H35, H36, H37, H38, H39, H40, H41, H42, H43, H44, H45, H46, H47, H48, H49, H50, H51, H52, H53, H54, H55, H56, H57, H58, H59, H60, H61, H62, H63, H64: STAND-OFF
J1, J9, J14, J19, J24, J29, J34, J39, J44, J49, J54, J59, J64, J69, J74, J79: USB-to-Serial; 1X06_NO_SILK
J2, J4, J6, J8, J11, J13, J16, J18, J21, J23, J26, J28, J31, J33, J36, J38, J41, J43, J46, J48, J51, J53, J56, J58, J61, J63, J66, J68, J71, J73, J76, J78: Qwiic RA; JST04_1MM_RA
J3, J7, J12, J17, J22, J27, J32, J37, J42, J47, J52, J57, J62, J67, J72, J77: PTH; 1X04_NO_SILK
J5, J10, J15, J20, J25, J30, J35, J40, J45, J50, J55, J60, J65, J70, J75, J80: 1X08_NO_SILK
JP1, JP2, JP3, JP4, JP5, JP6, JP7, JP8, JP9, JP10, JP11, JP12, JP13, JP14, JP15, JP16: JUMPER-SMT_3_NO_SILK; SMT-JUMPER_3_NO_SILK
LED1, LED2, LED3, LED4, LED5, LED6, LED7, LED8, LED9, LED10, LED11, LED12, LED13, LED14, LED15, LED16: RED; LED-0603
LOGO1, LOGO5, LOGO9, LOGO13, LOGO17, LOGO21, LOGO25, LOGO29, LOGO33, LOGO37, LOGO41, LOGO45, LOGO49, LOGO53, LOGO57, LOGO61: OSHW-LOGOMINI; OSHW-LOGO-MINI
LOGO2, LOGO6, LOGO10, LOGO14, LOGO18, LOGO22, LOGO26, LOGO30, LOGO34, LOGO38, LOGO42, LOGO46, LOGO50, LOGO54, LOGO58, LOGO62: SFE_LOGO_NAME_FLAME.1_INCH; SFE_LOGO_NAME_FLAME_.1
LOGO3, LOGO7, LOGO11, LOGO15, LOGO19, LOGO23, LOGO27, LOGO31, LOGO35, LOGO39, LOGO43, LOGO47, LOGO51, LOGO55, LOGO59, LOGO63: QWIIC_LOGO_5MM; QWIIC_5MM
LOGO4, LOGO8, LOGO12, LOGO16, LOGO20, LOGO24, LOGO28, LOGO32, LOGO36, LOGO40, LOGO44, LOGO48, LOGO52, LOGO56, LOGO60, LOGO64: SFE_LOGO_NAME.1_INCH; SFE_LOGO_NAME_.1
MEAS, MEAS1, MEAS2, MEAS3, MEAS4, MEAS5, MEAS6, MEAS7, MEAS8, MEAS9, MEAS10, MEAS11, MEAS12, MEAS13, MEAS14, MEAS15: JUMPER-COMBO_2_NC_TRACE; COMBO-JUMPER_2_NC_TRACE
PPS_LED, PPS_LED1, PPS_LED2, PPS_LED3, PPS_LED4, PPS_LED5, PPS_LED6, PPS_LED7, PPS_LED8, PPS_LED9, PPS_LED10, PPS_LED11, PPS_LED12, PPS_LED13, PPS_LED14, PPS_LED15: JUMPER-SMT_2_NC_TRACE_SILK; SMT-JUMPER_2_NC_TRACE_SILK
PWR, PWR1, PWR2, PWR3, PWR4, PWR5, PWR6, PWR7, PWR8, PWR9, PWR10, PWR11, PWR12, PWR13, PWR14, PWR15: JUMPER-SMT_2_NC_TRACE_SILK; SMT-JUMPER_2_NC_TRACE_SILK
R1, R11, R16, R23, R34, R37, R48, R51, R62, R65, R76, R79, R90, R93, R104, R107, R118, R121, R132, R135, R146, R149, R160, R163, R174, R177, R188, R191, R202, R205, R216, R219: 1k; 0603
R2, R3, R4, R6, R9, R10, R17, R18, R19, R20, R21, R22, R25, R26, R27, R28, R29, R30, R35, R36, R39, R40, R41, R42, R43, R44, R49, R50, R53, R54, R55, R56, R57, R58, R63, R64, R67, R68, R69, R70, R71, R72, R77, R78, R81, R82, R83, R84, R85, R86, R91, R92, R95, R96, R97, R98, R99, R100, R105, R106, R109, R110, R111, R112, R113, R114, R119, R120, R123, R124, R125, R126, R127, R128, R133, R134, R137, R138, R139, R140, R141, R142, R147, R148, R151, R152, R153, R154, R155, R156, R161, R162, R165, R166, R167, R168, R169, R170, R175, R176, R179, R180, R181, R182, R183, R184, R189, R190, R193, R194, R195, R196, R197, R198, R203, R204, R207, R208, R209, R210, R211, R212, R217, R218, R221, R222, R223, R224: 33; 0603
R5, R15, R33, R47, R61, R75, R89, R103, R117, R131, R145, R159, R173, R187, R201, R215: 3.3k; 0603
R7, R8, R12, R13, R31, R32, R45, R46, R59, R60, R73, R74, R87, R88, R101, R102, R115, R116, R129, R130, R143, R144, R157, R158, R171, R172, R185, R186, R199, R200, R213, R214: 2.2k; 0603
R14, R24, R38, R52, R66, R80, R94, R108, R122, R136, R150, R164, R178, R192, R206, R220: 33OHM-0402T-1/10W-1%; 0402-TIGHT
U1, U2, U3, U4, U5, U6, U7, U8, U9, U10, U11, U12, U13, U14, U15, U16: MAX-M10S
U$1, U$2, U$10, U$26, U$31, U$53, U$67, U$74, U$89, U$97, U$111, U$118, U$133, U$141, U$155, U$162, U$177, U$185, U$199, U$206, U$221, U$229, U$243, U$250, U$265, U$273, U$287, U$294, U$309, U$317, U$331, U$338, U$353, U$361, U$375, U$382, U$397, U$405, U$419, U$426, U$441, U$449, U$463, U$470, U$485, U$493, U$507, U$514, U$529, U$537, U$551, U$558, U$573, U$581, U$595, U$602, U$617, U$625, U$639, U$646, U$661, U$669, U$683, U$690: #3V3#4
U$3, U$11, U$17, U$27, U$34, U$54, U$68, U$75, U$90, U$98, U$112, U$119, U$134, U$142, U$156, U$163, U$178, U$186, U$200, U$207, U$222, U$230, U$244, U$251, U$266, U$274, U$288, U$295, U$310, U$318, U$332, U$339, U$354, U$362, U$376, U$383, U$398, U$406, U$420, U$427, U$442, U$450, U$464, U$471, U$486, U$494, U$508, U$515, U$530, U$538, U$552, U$559, U$574, U$582, U$596, U$603, U$618, U$626, U$640, U$647, U$662, U$670, U$684, U$691: #GND#5
U$4, U$28, U$47, U$69, U$91, U$113, U$135, U$157, U$179, U$201, U$223, U$245, U$267, U$289, U$311, U$333, U$355, U$377, U$399, U$421, U$443, U$465, U$487, U$509, U$531, U$553, U$575, U$597, U$619, U$641, U$663, U$685: BLK0
U$5, U$29, U$48, U$70, U$92, U$114, U$136, U$158, U$180, U$202, U$224, U$246, U$268, U$290, U$312, U$334, U$356, U$378, U$400, U$422, U$444, U$466, U$488, U$510, U$532, U$554, U$576, U$598, U$620, U$642, U$664, U$686: GRN1
U$6, U$49, U$93, U$137, U$181, U$225, U$269, U$313, U$357, U$401, U$445, U$489, U$533, U$577, U$621, U$665: PPS7
U$7, U$50, U$94, U$138, U$182, U$226, U$270, U$314, U$358, U$402, U$446, U$490, U$534, U$578, U$622, U$666: PWR6
U$8, U$25, U$51, U$66, U$95, U$110, U$139, U$154, U$183, U$198, U$227, U$242, U$271, U$286, U$315, U$330, U$359, U$374, U$403, U$418, U$447, U$462, U$491, U$506, U$535, U$550, U$579, U$594, U$623, U$638, U$667, U$682: #RX#2
U$9, U$22, U$52, U$65, U$96, U$109, U$140, U$153, U$184, U$197, U$228, U$241, U$272, U$285, U$316, U$329, U$360, U$373, U$404, U$417, U$448, U$461, U$492, U$505, U$536, U$549, U$580, U$593, U$624, U$637, U$668, U$681: #TX#3
U$12, U$55, U$99, U$143, U$187, U$231, U$275, U$319, U$363, U$407, U$451, U$495, U$539, U$583, U$627, U$671: ##RST##2
U$13, U$56, U$100, U$144, U$188, U$232, U$276, U$320, U$364, U$408, U$452, U$496, U$540, U$584, U$628, U$672: ##SAFE##0
U$14, U$43, U$57, U$82, U$101, U$126, U$145, U$170, U$189, U$214, U$233, U$258, U$277, U$302, U$321, U$346, U$365, U$390, U$409, U$434, U$453, U$478, U$497, U$522, U$541, U$566, U$585, U$610, U$629, U$654, U$673, U$698: #PPS#1
U$15, U$58, U$102, U$146, U$190, U$234, U$278, U$322, U$366, U$410, U$454, U$498, U$542, U$586, U$630, U$674: #RX#1
U$16, U$59, U$103, U$147, U$191, U$235, U$279, U$323, U$367, U$411, U$455, U$499, U$543, U$587, U$631, U$675: #TX#0
U$18, U$23, U$60, U$63, U$104, U$107, U$148, U$151, U$192, U$195, U$236, U$239, U$280, U$283, U$324, U$327, U$368, U$371, U$412, U$415, U$456, U$459, U$500, U$503, U$544, U$547, U$588, U$591, U$632, U$635, U$676, U$679: MAX#M10S1
U$19, U$37, U$78, U$85, U$122, U$129, U$166, U$173, U$210, U$217, U$254, U$261, U$298, U$305, U$342, U$349, U$386, U$393, U$430, U$437, U$474, U$481, U$518, U$525, U$562, U$569, U$606, U$613, U$650, U$657, U$694, U$701: #0
U$20, U$21, U$61, U$62, U$105, U$106, U$149, U$150, U$193, U$194, U$237, U$238, U$281, U$282, U$325, U$326, U$369, U$370, U$413, U$414, U$457, U$458, U$501, U$502, U$545, U$546, U$589, U$590, U$633, U$634, U$677, U$678: U#BLOX0
U$24, U$64, U$108, U$152, U$196, U$240, U$284, U$328, U$372, U$416, U$460, U$504, U$548, U$592, U$636, U$680: SMA2
U$30, U$71, U$115, U$159, U$203, U$247, U$291, U$335, U$379, U$423, U$467, U$511, U$555, U$599, U$643, U$687: #I�C#0
U$32, U$72, U$116, U$160, U$204, U$248, U$292, U$336, U$380, U$424, U$468, U$512, U$556, U$600, U$644, U$688: #SCL#1
U$33, U$73, U$117, U$161, U$205, U$249, U$293, U$337, U$381, U$425, U$469, U$513, U$557, U$601, U$645, U$689: #SDA#0
U$35, U$76, U$120, U$164, U$208, U$252, U$296, U$340, U$384, U$428, U$472, U$516, U$560, U$604, U$648, U$692: #PPS#0
U$36, U$77, U$121, U$165, U$209, U$253, U$297, U$341, U$385, U$429, U$473, U$517, U$561, U$605, U$649, U$693: #PWR#0
U$38, U$40, U$79, U$86, U$123, U$130, U$167, U$174, U$211, U$218, U$255, U$262, U$299, U$306, U$343, U$350, U$387, U$394, U$431, U$438, U$475, U$482, U$519, U$526, U$563, U$570, U$607, U$614, U$651, U$658, U$695, U$702: #1
U$39, U$80, U$124, U$168, U$212, U$256, U$300, U$344, U$388, U$432, U$476, U$520, U$564, U$608, U$652, U$696: ##RST##0
U$41, U$87, U$131, U$175, U$219, U$263, U$307, U$351, U$395, U$439, U$483, U$527, U$571, U$615, U$659, U$703: #MEAS#0
U$42, U$81, U$125, U$169, U$213, U$257, U$301, U$345, U$389, U$433, U$477, U$521, U$565, U$609, U$653, U$697: #EINT#0
U$44, U$83, U$127, U$171, U$215, U$259, U$303, U$347, U$391, U$435, U$479, U$523, U$567, U$611, U$655, U$699: RX2
U$45, U$84, U$128, U$172, U$216, U$260, U$304, U$348, U$392, U$436, U$480, U$524, U$568, U$612, U$656, U$700: TX3
U$46, U$88, U$132, U$176, U$220, U$264, U$308, U$352, U$396, U$440, U$484, U$528, U$572, U$616, U$660, U$704: #EINT_#0

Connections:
3.3V: D2.A, J2.2, J3.2, J4.2, J5.2, JP5.2, MEAS.2, MEAS.4, PWR.2, U1.7, U1.8
3.3V1: D4.A, J6.2, J7.2, J8.2, J10.2, JP1.2, MEAS1.2, MEAS1.4, PWR1.2, U2.7, U2.8
3.3V2: D7.A, J11.2, J12.2, J13.2, J15.2, JP2.2, MEAS2.2, MEAS2.4, PWR2.2, U3.7, U3.8
3.3V3: D11.A, J16.2, J17.2, J18.2, J20.2, JP3.2, MEAS3.2, MEAS3.4, PWR3.2, U4.7, U4.8
3.3V4: D14.A, J21.2, J22.2, J23.2, J25.2, JP4.2, MEAS4.2, MEAS4.4, PWR4.2, U5.7, U5.8
3.3V5: D17.A, J26.2, J27.2, J28.2, J30.2, JP6.2, MEAS5.2, MEAS5.4, PWR5.2, U6.7, U6.8
3.3V6: D20.A, J31.2, J32.2, J33.2, J35.2, JP7.2, MEAS6.2, MEAS6.4, PWR6.2, U7.7, U7.8
3.3V7: D23.A, J36.2, J37.2, J38.2, J40.2, JP8.2, MEAS7.2, MEAS7.4, PWR7.2, U8.7, U8.8
3.3V8: D26.A, J41.2, J42.2, J43.2, J45.2, JP9.2, MEAS8.2, MEAS8.4, PWR8.2, U9.7, U9.8
3.3V9: D29.A, J46.2, J47.2, J48.2, J50.2, JP10.2, MEAS9.2, MEAS9.4, PWR9.2, U10.7, U10.8
3.3V10: D32.A, J51.2, J52.2, J53.2, J55.2, JP11.2, MEAS10.2, MEAS10.4, PWR10.2, U11.7, U11.8
3.3V11: D35.A, J56.2, J57.2, J58.2, J60.2, JP12.2, MEAS11.2, MEAS11.4, PWR11.2, U12.7, U12.8
3.3V12: D38.A, J61.2, J62.2, J63.2, J65.2, JP13.2, MEAS12.2, MEAS12.4, PWR12.2, U13.7, U13.8
3.3V13: D41.A, J66.2, J67.2, J68.2, J70.2, JP14.2, MEAS13.2, MEAS13.4, PWR13.2, U14.7, U14.8
3.3V14: D44.A, J71.2, J72.2, J73.2, J75.2, JP15.2, MEAS14.2, MEAS14.4, PWR14.2, U15.7, U15.8
3.3V15: D47.A, J76.2, J77.2, J78.2, J80.2, JP16.2, MEAS15.2, MEAS15.4, PWR15.2, U16.7, U16.8
!RESET: J5.8, R19.2
!RESET1: J10.8, R26.2
!RESET2: J15.8, R40.2
!RESET3: J20.8, R54.2
!RESET4: J25.8, R68.2
!RESET5: J30.8, R82.2
!RESET6: J35.8, R96.2
!RESET7: J40.8, R110.2
!RESET8: J45.8, R124.2
!RESET9: J50.8, R138.2
!RESET10: J55.8, R152.2
!RESET11: J60.8, R166.2
!RESET12: J65.8, R180.2
!RESET13: J70.8, R194.2
!RESET14: J75.8, R208.2
!RESET15: J80.8, R222.2
!SAFE: J5.3, R20.2
!SAFE1: J10.3, R27.2
!SAFE2: J15.3, R41.2
!SAFE3: J20.3, R55.2
!SAFE4: J25.3, R69.2
!SAFE5: J30.3, R83.2
!SAFE6: J35.3, R97.2
!SAFE7: J40.3, R111.2
!SAFE8: J45.3, R125.2
!SAFE9: J50.3, R139.2
!SAFE10: J55.3, R153.2
!SAFE11: J60.3, R167.2
!SAFE12: J65.3, R181.2
!SAFE13: J70.3, R195.2
!SAFE14: J75.3, R209.2
!SAFE15: J80.3, R223.2
ANT_VCC: C1.1, FB2.2, R14.1
ANT_VCC1: C4.1, FB1.2, R24.1
ANT_VCC2: C6.1, FB3.2, R38.1
ANT_VCC3: C8.1, FB4.2, R52.1
ANT_VCC4: C10.1, FB5.2, R66.1
ANT_VCC5: C12.1, FB6.2, R80.1
ANT_VCC6: C14.1, FB7.2, R94.1
ANT_VCC7: C16.1, FB8.2, R108.1
ANT_VCC8: C18.1, FB9.2, R122.1
ANT_VCC9: C20.1, FB10.2, R136.1
ANT_VCC10: C22.1, FB11.2, R150.1
ANT_VCC11: C24.1, FB12.2, R164.1
ANT_VCC12: C26.1, FB13.2, R178.1
ANT_VCC13: C28.1, FB14.2, R192.1
ANT_VCC14: C30.1, FB15.2, R206.1
ANT_VCC15: C32.1, FB16.2, R220.1
BACKUP: B1.+, C3.1, R5.1, U1.6
BACKUP1: B2.+, C2.1, R15.1, U2.6
BACKUP2: B3.+, C5.1, R33.1, U3.6
BACKUP3: B4.+, C7.1, R47.1, U4.6
BACKUP4: B5.+, C9.1, R61.1, U5.6
BACKUP5: B6.+, C11.1, R75.1, U6.6
BACKUP6: B7.+, C13.1, R89.1, U7.6
BACKUP7: B8.+, C15.1, R103.1, U8.6
BACKUP8: B9.+, C17.1, R117.1, U9.6
BACKUP9: B10.+, C19.1, R131.1, U10.6
BACKUP10: B11.+, C21.1, R145.1, U11.6
BACKUP11: B12.+, C23.1, R159.1, U12.6
BACKUP12: B13.+, C25.1, R173.1, U13.6
BACKUP13: B14.+, C27.1, R187.1, U14.6
BACKUP14: B15.+, C29.1, R201.1, U15.6
BACKUP15: B16.+, C31.1, R215.1, U16.6
EXTINT_LV: R18.1, U1.5
EXTINT_LV1: R25.1, U2.5
EXTINT_LV2: R39.1, U3.5
EXTINT_LV3: R53.1, U4.5
EXTINT_LV4: R67.1, U5.5
EXTINT_LV5: R81.1, U6.5
EXTINT_LV6: R95.1, U7.5
EXTINT_LV7: R109.1, U8.5
EXTINT_LV8: R123.1, U9.5
EXTINT_LV9: R137.1, U10.5
EXTINT_LV10: R151.1, U11.5
EXTINT_LV11: R165.1, U12.5
EXTINT_LV12: R179.1, U13.5
EXTINT_LV13: R193.1, U14.5
EXTINT_LV14: R207.1, U15.5
EXTINT_LV15: R221.1, U16.5
GND: B1.-, C1.2, C3.2, D1.C, D10.2, E1.GND@0, E1.GND@1, E1.GND@2, E1.GND@3, J1.6, J2.1, J3.1, J4.1, J5.1, LED2.C, U1.1, U1.10, U1.12
GND1: B2.-, C2.2, C4.2, D3.C, D5.2, E2.GND@0, E2.GND@1, E2.GND@2, E2.GND@3, J6.1, J7.1, J8.1, J9.6, J10.1, LED1.C, U2.1, U2.10, U2.12
GND2: B3.-, C5.2, C6.2, D6.C, D8.2, E3.GND@0, E3.GND@1, E3.GND@2, E3.GND@3, J11.1, J12.1, J13.1, J14.6, J15.1, LED3.C, U3.1, U3.10, U3.12
GND3: B4.-, C7.2, C8.2, D9.C, D12.2, E4.GND@0, E4.GND@1, E4.GND@2, E4.GND@3, J16.1, J17.1, J18.1, J19.6, J20.1, LED4.C, U4.1, U4.10, U4.12
GND4: B5.-, C9.2, C10.2, D13.C, D15.2, E5.GND@0, E5.GND@1, E5.GND@2, E5.GND@3, J21.1, J22.1, J23.1, J24.6, J25.1, LED5.C, U5.1, U5.10, U5.12
GND5: B6.-, C11.2, C12.2, D16.C, D18.2, E6.GND@0, E6.GND@1, E6.GND@2, E6.GND@3, J26.1, J27.1, J28.1, J29.6, J30.1, LED6.C, U6.1, U6.10, U6.12
GND6: B7.-, C13.2, C14.2, D19.C, D21.2, E7.GND@0, E7.GND@1, E7.GND@2, E7.GND@3, J31.1, J32.1, J33.1, J34.6, J35.1, LED7.C, U7.1, U7.10, U7.12
GND7: B8.-, C15.2, C16.2, D22.C, D24.2, E8.GND@0, E8.GND@1, E8.GND@2, E8.GND@3, J36.1, J37.1, J38.1, J39.6, J40.1, LED8.C, U8.1, U8.10, U8.12
GND8: B9.-, C17.2, C18.2, D25.C, D27.2, E9.GND@0, E9.GND@1, E9.GND@2, E9.GND@3, J41.1, J42.1, J43.1, J44.6, J45.1, LED9.C, U9.1, U9.10, U9.12
GND9: B10.-, C19.2, C20.2, D28.C, D30.2, E10.GND@0, E10.GND@1, E10.GND@2, E10.GND@3, J46.1, J47.1, J48.1, J49.6, J50.1, LED10.C, U10.1, U10.10, U10.12
GND10: B11.-, C21.2, C22.2, D31.C, D33.2, E11.GND@0, E11.GND@1, E11.GND@2, E11.GND@3, J51.1, J52.1, J53.1, J54.6, J55.1, LED11.C, U11.1, U11.10, U11.12
GND11: B12.-, C23.2, C24.2, D34.C, D36.2, E12.GND@0, E12.GND@1, E12.GND@2, E12.GND@3, J56.1, J57.1, J58.1, J59.6, J60.1, LED12.C, U12.1, U12.10, U12.12
GND12: B13.-, C25.2, C26.2, D37.C, D39.2, E13.GND@0, E13.GND@1, E13.GND@2, E13.GND@3, J61.1, J62.1, J63.1, J64.6, J65.1, LED13.C, U13.1, U13.10, U13.12
GND13: B14.-, C27.2, C28.2, D40.C, D42.2, E14.GND@0, E14.GND@1, E14.GND@2, E14.GND@3, J66.1, J67.1, J68.1, J69.6, J70.1, LED14.C, U14.1, U14.10, U14.12
GND14: B15.-, C29.2, C30.2, D43.C, D45.2, E15.GND@0, E15.GND@1, E15.GND@2, E15.GND@3, J71.1, J72.1, J73.1, J74.6, J75.1, LED15.C, U15.1, U15.10, U15.12
GND15: B16.-, C31.2, C32.2, D46.C, D48.2, E16.GND@0, E16.GND@1, E16.GND@2, E16.GND@3, J76.1, J77.1, J78.1, J79.6, J80.1, LED16.C, U16.1, U16.10, U16.12
GPS_RF: D10.1, E1.SIG, FB2.1, U1.11
GPS_RF1: D5.1, E2.SIG, FB1.1, U2.11
GPS_RF2: D8.1, E3.SIG, FB3.1, U3.11
GPS_RF3: D12.1, E4.SIG, FB4.1, U4.11
GPS_RF4: D15.1, E5.SIG, FB5.1, U5.11
GPS_RF5: D18.1, E6.SIG, FB6.1, U6.11
GPS_RF6: D21.1, E7.SIG, FB7.1, U7.11
GPS_RF7: D24.1, E8.SIG, FB8.1, U8.11
GPS_RF8: D27.1, E9.SIG, FB9.1, U9.11
GPS_RF9: D30.1, E10.SIG, FB10.1, U10.11
GPS_RF10: D33.1, E11.SIG, FB11.1, U11.11
GPS_RF11: D36.1, E12.SIG, FB12.1, U12.11
GPS_RF12: D39.1, E13.SIG, FB13.1, U13.11
GPS_RF13: D42.1, E14.SIG, FB14.1, U14.11
GPS_RF14: D45.1, E15.SIG, FB15.1, U15.11
GPS_RF15: D48.1, E16.SIG, FB16.1, U16.11
INT: J5.7, R18.2
INT1: J10.7, R25.2
INT2: J15.7, R39.2
INT3: J20.7, R53.2
INT4: J25.7, R67.2
INT5: J30.7, R81.2
INT6: J35.7, R95.2
INT7: J40.7, R109.2
INT8: J45.7, R123.2
INT9: J50.7, R137.2
INT10: J55.7, R151.2
INT11: J60.7, R165.2
INT12: J65.7, R179.2
INT13: J70.7, R193.2
INT14: J75.7, R207.2
INT15: J80.7, R221.2
unnamed: J1.4, MEAS.1, MEAS.3
unnamed: D1.A, R11.1
unnamed: JP1.1, R13.2
unnamed: PPS_LED.1, R11.2
unnamed: JP5.1, R8.2
unnamed: D2.C, R5.2
unnamed: JP1.3, R12.2
unnamed: JP5.3, R7.2
unnamed: D3.A, R16.1
unnamed: LED2.A, R1.1
unnamed: PPS_LED1.1, R16.2
unnamed: D4.C, R15.2
unnamed: LED1.A, R23.1
unnamed: PWR1.1, R23.2
unnamed: J9.4, MEAS1.1, MEAS1.3
unnamed: JP2.1, R32.2
unnamed: PWR.1, R1.2
unnamed: JP2.3, R31.2
unnamed: D6.A, R34.1
unnamed: PPS_LED2.1, R34.2
unnamed: D7.C, R33.2
unnamed: LED3.A, R37.1
unnamed: PWR2.1, R37.2
unnamed: J14.4, MEAS2.1, MEAS2.3
unnamed: JP3.1, R46.2
unnamed: JP3.3, R45.2
unnamed: D9.A, R48.1
unnamed: PPS_LED3.1, R48.2
unnamed: D11.C, R47.2
unnamed: LED4.A, R51.1
unnamed: PWR3.1, R51.2
unnamed: J19.4, MEAS3.1, MEAS3.3
unnamed: JP4.1, R60.2
unnamed: JP4.3, R59.2
unnamed: D13.A, R62.1
unnamed: PPS_LED4.1, R62.2
unnamed: D14.C, R61.2
unnamed: LED5.A, R65.1
unnamed: PWR4.1, R65.2
unnamed: J24.4, MEAS4.1, MEAS4.3
unnamed: JP6.1, R74.2
unnamed: JP6.3, R73.2
unnamed: D16.A, R76.1
unnamed: PPS_LED5.1, R76.2
unnamed: D17.C, R75.2
unnamed: LED6.A, R79.1
unnamed: PWR5.1, R79.2
unnamed: J29.4, MEAS5.1, MEAS5.3
unnamed: JP7.1, R88.2
unnamed: JP7.3, R87.2
unnamed: D19.A, R90.1
unnamed: PPS_LED6.1, R90.2
unnamed: D20.C, R89.2
unnamed: LED7.A, R93.1
unnamed: PWR6.1, R93.2
unnamed: J34.4, MEAS6.1, MEAS6.3
unnamed: JP8.1, R102.2
unnamed: JP8.3, R101.2
unnamed: D22.A, R104.1
unnamed: PPS_LED7.1, R104.2
unnamed: D23.C, R103.2
unnamed: LED8.A, R107.1
unnamed: PWR7.1, R107.2
unnamed: J39.4, MEAS7.1, MEAS7.3
unnamed: JP9.1, R116.2
unnamed: JP9.3, R115.2
unnamed: D25.A, R118.1
unnamed: PPS_LED8.1, R118.2
unnamed: D26.C, R117.2
unnamed: LED9.A, R121.1
unnamed: PWR8.1, R121.2
unnamed: J44.4, MEAS8.1, MEAS8.3
unnamed: JP10.1, R130.2
unnamed: JP10.3, R129.2
unnamed: D28.A, R132.1
unnamed: PPS_LED9.1, R132.2
unnamed: D29.C, R131.2
unnamed: LED10.A, R135.1
unnamed: PWR9.1, R135.2
unnamed: J49.4, MEAS9.1, MEAS9.3
unnamed: JP11.1, R144.2
unnamed: JP11.3, R143.2
unnamed: D31.A, R146.1
unnamed: PPS_LED10.1, R146.2
unnamed: D32.C, R145.2
unnamed: LED11.A, R149.1
unnamed: PWR10.1, R149.2
unnamed: J54.4, MEAS10.1, MEAS10.3
unnamed: JP12.1, R158.2
unnamed: JP12.3, R157.2
unnamed: D34.A, R160.1
unnamed: PPS_LED11.1, R160.2
unnamed: D35.C, R159.2
unnamed: LED12.A, R163.1
unnamed: PWR11.1, R163.2
unnamed: J59.4, MEAS11.1, MEAS11.3
unnamed: JP13.1, R172.2
unnamed: JP13.3, R171.2
unnamed: D37.A, R174.1
unnamed: PPS_LED12.1, R174.2
unnamed: D38.C, R173.2
unnamed: LED13.A, R177.1
unnamed: PWR12.1, R177.2
unnamed: J64.4, MEAS12.1, MEAS12.3
unnamed: JP14.1, R186.2
unnamed: JP14.3, R185.2
unnamed: D40.A, R188.1
unnamed: PPS_LED13.1, R188.2
unnamed: D41.C, R187.2
unnamed: LED14.A, R191.1
unnamed: PWR13.1, R191.2
unnamed: J69.4, MEAS13.1, MEAS13.3
unnamed: JP15.1, R200.2
unnamed: JP15.3, R199.2
unnamed: D43.A, R202.1
unnamed: PPS_LED14.1, R202.2
unnamed: D44.C, R201.2
unnamed: LED15.A, R205.1
unnamed: PWR14.1, R205.2
unnamed: J74.4, MEAS14.1, MEAS14.3
unnamed: JP16.1, R214.2
unnamed: JP16.3, R213.2
unnamed: D46.A, R216.1
unnamed: PPS_LED15.1, R216.2
unnamed: D47.C, R215.2
unnamed: LED16.A, R219.1
unnamed: PWR15.1, R219.2
unnamed: J79.4, MEAS15.1, MEAS15.3
PPS: J5.6, PPS_LED.2, R21.2
PPS1: J10.6, PPS_LED1.2, R28.2
PPS2: J15.6, PPS_LED2.2, R42.2
PPS3: J20.6, PPS_LED3.2, R56.2
PPS4: J25.6, PPS_LED4.2, R70.2
PPS5: J30.6, PPS_LED5.2, R84.2
PPS6: J35.6, PPS_LED6.2, R98.2
PPS7: J40.6, PPS_LED7.2, R112.2
PPS8: J45.6, PPS_LED8.2, R126.2
PPS9: J50.6, PPS_LED9.2, R140.2
PPS10: J55.6, PPS_LED10.2, R154.2
PPS11: J60.6, PPS_LED11.2, R168.2
PPS12: J65.6, PPS_LED12.2, R182.2
PPS13: J70.6, PPS_LED13.2, R196.2
PPS14: J75.6, PPS_LED14.2, R210.2
PPS15: J80.6, PPS_LED15.2, R224.2
PPS_LV: R21.1, U1.4
PPS_LV1: R28.1, U2.4
PPS_LV2: R42.1, U3.4
PPS_LV3: R56.1, U4.4
PPS_LV4: R70.1, U5.4
PPS_LV5: R84.1, U6.4
PPS_LV6: R98.1, U7.4
PPS_LV7: R112.1, U8.4
PPS_LV8: R126.1, U9.4
PPS_LV9: R140.1, U10.4
PPS_LV10: R154.1, U11.4
PPS_LV11: R168.1, U12.4
PPS_LV12: R182.1, U13.4
PPS_LV13: R196.1, U14.4
PPS_LV14: R210.1, U15.4
PPS_LV15: R224.1, U16.4
RST_LV: R19.1, U1.9
RST_LV1: R26.1, U2.9
RST_LV2: R40.1, U3.9
RST_LV3: R54.1, U4.9
RST_LV4: R68.1, U5.9
RST_LV5: R82.1, U6.9
RST_LV6: R96.1, U7.9
RST_LV7: R110.1, U8.9
RST_LV8: R124.1, U9.9
RST_LV9: R138.1, U10.9
RST_LV10: R152.1, U11.9
RST_LV11: R166.1, U12.9
RST_LV12: R180.1, U13.9
RST_LV13: R194.1, U14.9
RST_LV14: R208.1, U15.9
RST_LV15: R222.1, U16.9
RXI: J1.3, J5.5, R6.2
RXI1: J9.3, J10.5, R10.2
RXI2: J14.3, J15.5, R30.2
RXI3: J19.3, J20.5, R44.2
RXI4: J24.3, J25.5, R58.2
RXI5: J29.3, J30.5, R72.2
RXI6: J34.3, J35.5, R86.2
RXI7: J39.3, J40.5, R100.2
RXI8: J44.3, J45.5, R114.2
RXI9: J49.3, J50.5, R128.2
RXI10: J54.3, J55.5, R142.2
RXI11: J59.3, J60.5, R156.2
RXI12: J64.3, J65.5, R170.2
RXI13: J69.3, J70.5, R184.2
RXI14: J74.3, J75.5, R198.2
RXI15: J79.3, J80.5, R212.2
RXLV: R6.1, U1.3
RXLV1: R10.1, U2.3
RXLV2: R30.1, U3.3
RXLV3: R44.1, U4.3
RXLV4: R58.1, U5.3
RXLV5: R72.1, U6.3
RXLV6: R86.1, U7.3
RXLV7: R100.1, U8.3
RXLV8: R114.1, U9.3
RXLV9: R128.1, U10.3
RXLV10: R142.1, U11.3
RXLV11: R156.1, U12.3
RXLV12: R170.1, U13.3
RXLV13: R184.1, U14.3
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

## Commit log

2021-03-10 Changing RF path to 0402. Adding GND vias on both RF trace sides. Adding panel.
    [SparkFun u-blox GNSS MAX-M10S-Panel.GBL, SparkFun u-blox GNSS MAX-M10S-Panel.GBO, SparkFun u-blox GNSS MAX-M10S-Panel.GBP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]
2021-11-15 Add ESD RF diode. Change to PTH SMA.
    [SparkFun u-blox GNSS MAX-M10S-Panel.GBL, SparkFun u-blox GNSS MAX-M10S-Panel.GBO, SparkFun u-blox GNSS MAX-M10S-Panel.GBP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]
2021-11-15 Add panel files
    [SparkFun u-blox GNSS MAX-M10S-Panel.GBL, SparkFun u-blox GNSS MAX-M10S-Panel.GBO, SparkFun u-blox GNSS MAX-M10S-Panel.GBP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]
2022-10-20 Convert boostrap buttons to mkdocs buttons
2022-10-20 Center buttons
2022-10-20 Adjust <div> to center button
2022-10-20 adjust boostrap buttons to mkdocs buttons
2022-10-20 Test primary button color alternative
2022-10-20 adjust button attribute for alternative color
2022-10-20 Insert Learn.SparkFun.com tutorials as tutorial tiles in a grid

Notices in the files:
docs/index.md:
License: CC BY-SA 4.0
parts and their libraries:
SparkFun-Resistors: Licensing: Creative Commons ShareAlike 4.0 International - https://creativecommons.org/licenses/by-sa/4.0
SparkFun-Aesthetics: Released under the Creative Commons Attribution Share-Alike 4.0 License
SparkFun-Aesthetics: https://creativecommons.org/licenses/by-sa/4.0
